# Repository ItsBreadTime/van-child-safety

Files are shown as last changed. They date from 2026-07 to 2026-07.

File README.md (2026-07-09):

# School Van Child Left-Behind Monitoring and Alert System

Prototype ESP32-based van child-safety monitor using BLE beacons, cabin sensors, MQTT/Home Assistant, and operator alerts for child-left-in-vehicle risk.

> Safety note: this is a research/prototype system, not a certified safety product. Do not rely on it as the only way to verify that a vehicle is empty. A physical cabin check and responsible operator procedure remain required.

## What It Does

- Reads ignition state from an ESP-NOW ignition remote or a protected GPIO input.
- Tracks cabin evidence from BLE iBeacon tags, LD2412 mmWave presence, SCD4x CO2, SHT4x temperature/humidity, and optional GPS.
- Publishes telemetry, state, roster, command, and distress topics over MQTT.
- Integrates with Home Assistant through MQTT discovery and optional YAML templates.
- Sends readable Discord bot alerts through a local Python relay.
- Supports guarded disarm workflows that require explicit cabin-clear confirmation.

## Repository Layout

```text
main/                 ESP-IDF firmware for the main ESP32-S3 unit
ignition_remote/      ESP-NOW heartbeat firmware for an ignition-powered remote
discord_relay/        Python Discord/MQTT relay with tests and Docker support
homeassistant/        Sanitized Home Assistant package/dashboard templates
hardware/             PCB, enclosure, and manufacturing/export files
docs/                 Public setup, configuration, protocol, and safety docs
test_runs/            Sanitized validation evidence and raw logs
```

The Android/mobile beacon app, thesis/report narrative drafts, private configs, generated office documents, and unsanitized runtime artifacts are intentionally not included in this public export. Sanitized validation evidence is included under [test_runs](test_runs/).

## Quick Start

1. Install ESP-IDF 5.x for `esp32s3`.
2. Copy `main/secrets.h.example` to `main/secrets.h` and fill in your own Wi-Fi, WireGuard, MQTT, and OTA values.
3. Build the firmware:

```bash
idf.py set-target esp32s3
idf.py build
```

4. Flash over USB:

```bash
idf.py -p /dev/cu.usbserial-XXXX flash monitor
```

5. Configure the relay:

```bash
cd discord_relay
cp .env.example .env
docker compose up -d --build
```

See [docs/SETUP.md](docs/SETUP.md) for the full setup path.

## Documentation

- [Setup](docs/SETUP.md)
- [Configuration](docs/CONFIGURATION.md)
- [MQTT contract](docs/MQTT.md)
- [Home Assistant templates](docs/HOME_ASSISTANT.md)
- [Hardware](docs/HARDWARE.md)
- [Flashing and OTA](docs/FLASHING.md)
- [Safety model](docs/SAFETY.md)
- [Sanitized test evidence](test_runs/)

## Tests

```bash
python -m pip install -r discord_relay/requirements.txt -r discord_relay/requirements-test.txt
python -m pytest discord_relay/tests -q
```

## License

Software is licensed under the Apache License 2.0. Hardware design files under `hardware/` are licensed under CERN-OHL-S v2; see [hardware/LICENSE](hardware/LICENSE).

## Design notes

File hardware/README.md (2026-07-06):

# Hardware Design

Hardware source and manufacturing/export files for the Van Child Safety prototype.

| Subdir | Source tool | Contents |
|---|---|---|
| `pcb/` | EasyEDA | Schematic, PCB render, Gerbers, EasyEDA JSON |
| `enclosure/` | Onshape | STEP/STL enclosure exports and assembly render |

## License

Hardware designs in this directory are licensed under CERN-OHL-S v2. See `hardware/LICENSE`.

Software in the rest of the repository is licensed under Apache 2.0.

## Notes

The PCB and enclosure files are provided as prototype artifacts. Validate footprints, clearances, power, thermal behavior, sensor placement, and enclosure materials before adapting them for a real vehicle.

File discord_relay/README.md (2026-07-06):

# Discord Relay

Dockerized Python relay that subscribes to the Van Child Safety MQTT topics, sends Discord bot alerts, and optionally exposes operator-only slash commands for status, guarded disarm, and beacon roster management.

## Setup

```bash
cp .env.example .env
docker compose up -d --build
```

Configure `.env` with your own MQTT broker, Discord bot token, channel IDs, and operator allow-list values.

## MQTT Inputs

- `bus/state`
- `bus/telemetry`
- `bus/beacon/+/state`
- `bus/beacon/config/state`
- `bus/distress/state`
- `bus/event`
- `bus/ha/location/event`
- `bus/ha/location/state`
- `bus/command/result`
- `bus/beacon/config/result`

## MQTT Outputs

- `bus/relay/discord/status`
- `bus/relay/discord/last_event`
- `bus/relay/discord/error`
- `bus/command`
- `bus/beacon/config/set`

## Operator Commands

Slash commands are disabled unless `DISCORD_COMMAND_GUILD_ID` and at least one operator user or role allow-list are configured.

- `/bus_status`
- `/disarm confirm:true`
- `/beacon list`
- `/beacon refresh`
- `/beacon add`
- `/beacon update`
- `/beacon active`
- `/beacon remove confirm:true`

`/disarm` is fail-closed: the caller must be allow-listed, `confirm` must be true, MQTT and firmware must be online, and success is shown only after matching firmware confirmation.

## Health And Metrics

The relay exposes:

- `GET /health`
- `GET /metrics`

The Docker image runs as a non-root user and writes logs/state under `/data`.

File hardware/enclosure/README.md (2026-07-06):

# Enclosure

Two-piece 3D-printed enclosure exports.

| File | Purpose |
|---|---|
| `top.step` | Top shell CAD export |
| `top.stl` | Top shell printable mesh |
| `bottom.step` | Bottom shell CAD export |
| `bottom.stl` | Bottom shell printable mesh |
| `assembly.png` | Assembly render |

STEP and STL exports preserve the final geometry, not the full parametric model history.

## Design Checks

- Keep antennas clear of metal.
- Do not block the LD2412 radar path with dense or metallic material.
- Give GPS a sky-facing path if used.
- Confirm heat, vibration, and mounting safety before any vehicle use.

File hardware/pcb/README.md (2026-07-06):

# PCB

PCB schematic, layout, and manufacturing exports.

| File | Purpose |
|---|---|
| `schematic.pdf` | Schematic export |
| `pcb.pdf` | PCB layout render |
| `pcb_top.pdf` | Top-side render |
| `pcb_bottom.pdf` | Bottom-side render |
| `gerber.zip` | Gerber manufacturing package |
| `pcb_easyeda.json` | EasyEDA-native editable source |
| `pcb_3d.obj` | Generated 3D board export |

Review all footprints, pin assignments, regulator/current limits, mounting holes, and connector clearances before manufacturing.

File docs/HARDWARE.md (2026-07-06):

# Hardware

The prototype uses:

- ESP32-S3 board with PSRAM
- SCD4x CO2 sensor
- SHT4x temperature/humidity sensor
- HLK-LD2412 mmWave presence sensor
- GPS receiver, optional
- BLE/iBeacon tags
- Ignition-powered ESP32 remote, optional but recommended
- Carrier PCB and 3D-printed enclosure under `hardware/`

## Main Firmware Pin Map

| Function | Default |
|---|---|
| I2C SDA | GPIO5 |
| I2C SCL | GPIO6 |
| LD2412 UART TX from ESP32 | GPIO7 |
| LD2412 UART RX to ESP32 | GPIO8 |
| GPS UART RX | GPIO9 |
| Legacy ignition GPIO | GPIO4 |

Check `main/Kconfig.projbuild` and the PCB files before wiring a different board.

## Enclosure Notes

- Keep the ESP32 antenna clear of metal.
- Give the GPS antenna a reasonable sky view if GPS is used.
- Do not place thick FR4 or metal directly in front of the LD2412 radar path.
- Validate thermal behavior and power stability in the actual enclosure before field use.

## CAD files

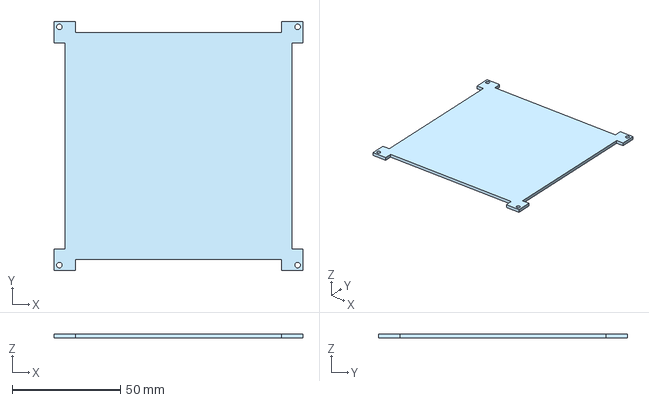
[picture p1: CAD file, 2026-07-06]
hardware/enclosure/bottom.step
115.0 x 115.0 x 2.00 mm

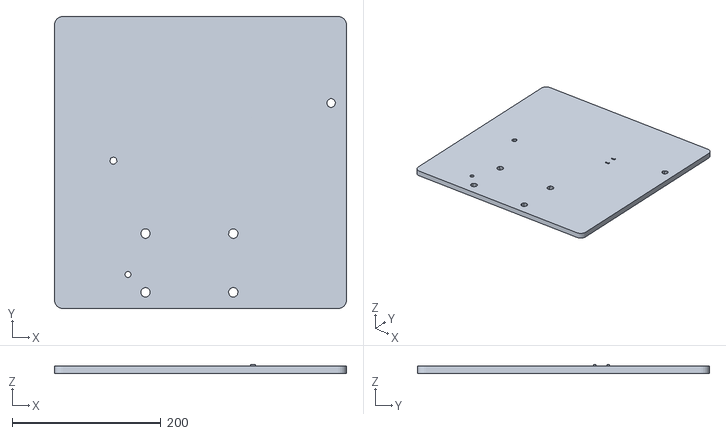
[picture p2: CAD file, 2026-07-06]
hardware/pcb/pcb_3d.obj
392.5 x 392.5 x 11.8

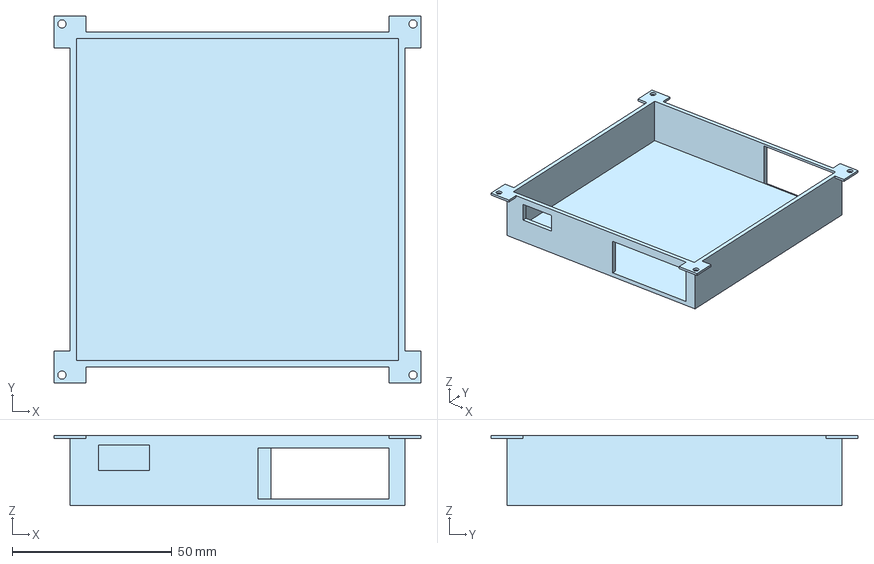
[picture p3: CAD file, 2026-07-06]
hardware/enclosure/top.step
115.0 x 115.0 x 22.0 mm

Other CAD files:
hardware/enclosure/bottom.stl
hardware/enclosure/top.stl

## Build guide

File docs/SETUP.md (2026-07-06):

# Setup

## Prerequisites

- ESP-IDF 5.x with ESP32-S3 support
- Python 3.12 for the relay and tests
- Docker or another Python runtime for the relay
- MQTT broker reachable from the firmware and relay
- Home Assistant with MQTT integration, if using the HA templates

## Firmware

```bash
cp main/secrets.h.example main/secrets.h
idf.py set-target esp32s3
idf.py menuconfig
idf.py build
idf.py -p /dev/cu.usbserial-XXXX flash monitor
```

Fill `main/secrets.h` with your own network, WireGuard, MQTT, and OTA values. Do not commit that file.

## Ignition Remote

The ignition remote is a separate ESP-IDF project. It broadcasts ESP-NOW heartbeats while powered by the vehicle ignition/accessory rail.

```bash
idf.py -C ignition_remote set-target esp32s3
idf.py -C ignition_remote menuconfig
idf.py -C ignition_remote -p /dev/cu.usbserial-XXXX flash monitor
```

The main firmware and remote firmware must use the same `ESPNOW_SECRET`.

## Discord Relay

```bash
cd discord_relay
cp .env.example .env
docker compose up -d --build
```

Set MQTT credentials, Discord bot token, channel IDs, and optional operator allow-lists in `.env`.

## Home Assistant

Start from the sanitized templates in `homeassistant/`. Adjust person/entity IDs, zone names, notification service names, and dashboard entity IDs for your own HA instance.

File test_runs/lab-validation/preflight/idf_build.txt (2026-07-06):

$ zsh -lc source '<local-path>' && idf.py build
# started_at=2026-07-04T19:00:24+07:00

Setting IDF_PATH to '<local-path>'
Detecting the Python interpreter
Checking "python3" ...
Python 3.14.4
"python3" has been detected
Checking Python compatibility
Checking other ESP-IDF version.
Adding ESP-IDF tools to PATH...
Checking if Python packages are up to date...
Python requirements are satisfied.
Constraint file: <local-path>
Requirement files:
 - <local-path>
Python being checked: <local-path>
Updated PATH variable:
  <local-path> Fusion.app/Contents/Public:<local-path>
Done! You can now compile ESP-IDF projects.
Go to the project directory and run:

  idf.py build

Executing action: all (aliases: build)
Running ninja in directory <local-path>
Executing "ninja all"...
[0/1] Re-running CMake...
-- Building ESP-IDF components for target esp32s3
NOTICE: Processing 2 dependencies:
NOTICE: [1/2] trombik/esp_wireguard (0.9.0)
NOTICE: [2/2] idf (5.3.3)
-- Project sdkconfig file <local-path>
Loading defaults file <local-path>
<local-path> CONFIG_APP_ROLLBACK_ENABLE was replaced with CONFIG_BOOTLOADER_APP_ROLLBACK_ENABLE 
-- Compiler supported targets: xtensa-esp-elf
CMake Deprecation Warning at <local-path> (cmake_minimum_required):
  Compatibility with CMake < 3.10 will be removed from a future version of
  CMake.

  Update the VERSION argument <min> value.  Or, use the <min>...<max> syntax
  to tell CMake that the project requires at least <min> but has been updated
  to work with policies introduced by <max> or earlier.

-- App "VanChildSafetySource" version: c19d455-dirty
-- Adding linker script <local-path>
-- Adding linker script <local-path>
-- Adding linker script <local-path>
-- Adding linker script <local-path>
-- Adding linker script <local-path>
-- Adding linker script <local-path>
-- Adding linker script <local-path>
-- Adding linker script <local-path>
-- Adding linker script <local-path>
-- Adding linker script <local-path>
-- Components: app_trace app_update bootloader bootloader_support bt cmock console cxx driver efuse esp-tls esp_adc esp_app_format esp_bootloader_format esp_coex esp_common esp_driver_ana_cmpr esp_driver_cam esp_driver_dac esp_driver_gpio esp_driver_gptimer esp_driver_i2c esp_driver_i2s esp_driver_isp esp_driver_jpeg esp_driver_ledc esp_driver_mcpwm esp_driver_parlio esp_driver_pcnt esp_driver_ppa esp_driver_rmt esp_driver_sdio esp_driver_sdm esp_driver_sdmmc esp_driver_sdspi esp_driver_spi esp_driver_touch_sens esp_driver_tsens esp_driver_uart esp_driver_usb_serial_jtag esp_eth esp_event esp_gdbstub esp_hid esp_http_client esp_http_server esp_https_ota esp_https_server esp_hw_support esp_lcd esp_local_ctrl esp_mm esp_netif esp_netif_stack esp_partition esp_phy esp_pm esp_psram esp_ringbuf esp_rom esp_system esp_timer esp_vfs_console esp_wifi espcoredump esptool_py fatfs freertos hal heap http_parser idf_test ieee802154 json log lwip main mbedtls mqtt newlib nvs_flash nvs_sec_provider openthread partition_table perfmon protobuf-c protocomm pthread sdmmc soc spi_flash spiffs tcp_transport touch_element trombik__esp_wireguard ulp unity usb vfs wear_levelling wifi_provisioning wpa_supplicant xtensa
-- Component paths: <local-path> <local-path> <local-path> <local-path> <local-path> <local-path> <local-path> <local-path> <local-path> <local-path> <local-path> <local-path> <local-path> <local-path> <local-path> <local-path> <local-path> <local-path> <local-path> <local-path> <local-path> <local-path> <local-path> <local-path> <local-path> <local-path> <local-path> <local-path> <local-path> <local-path> <local-path> <local-path> <local-path> <local-path> <local-path> <local-path> <local-path> <local-path> <local-path> <local-path> <local-path> <local-path> <local-path> <local-path> <local-path> <local-path> <local-path> <local-path> <local-path> <local-path> <local-path> <local-path> <local-path> <local-path> <local-path> <local-path> <local-path> <local-path> <local-path> <local-path> <local-path> <local-path> <local-path> <local-path> <local-path> <local-path> <local-path> <local-path> <local-path> <local-path> <local-path> <local-path> <local-path> <local-path> <local-path> <local-path> <local-path> <local-path> <local-path> <local-path> <local-path> <local-path> <local-path> <local-path> <local-path> <local-path> <local-path> <local-path> <local-path> <local-path> <local-path> <local-path> <local-path> <local-path> <local-path> <local-path> <local-path> <local-path> <local-path> <local-path> <local-path> <local-path> <local-path>
-- Configuring done (4.1s)
-- Generating done (0.4s)
-- Build files have been written to: <local-path>
[1/10] Performing build step for 'bootloader'
[1/1] cd <local-path> && <local-path> <local-path> --offset 0x8000 bootloader 0x0 <local-path>
Bootloader binary size 0x54e0 bytes. 0x2b20 bytes (34%) free.
[2/10] No install step for 'bootloader'
[3/10] Completed 'bootloader'
[4/10] Building C object esp-idf/esp_app_format/CMakeFiles/__idf_esp_app_format.dir/esp_app_desc.c.obj
[5/10] Linking C static library esp-idf/esp_app_format/libesp_app_format.a
[6/10] Generating ld/sections.ld
[7/10] Linking CXX executable VanChildSafetySource.elf
[8/10] Generating binary image from built executable
esptool.py v4.11.0
Creating esp32s3 image...
Merged 2 ELF sections
Successfully created esp32s3 image.
Generated <local-path>
[9/10] cd <local-path> && <local-path> <local-path> --offset 0x8000 partition --type app <local-path> <local-path>
VanChildSafetySource.bin binary size 0x176050 bytes. Smallest app partition is 0x300000 bytes. 0x189fb0 bytes (51%) free.

Project build complete. To flash, run:
 idf.py flash
or
 idf.py -p PORT flash
or
 python -m esptool --chip esp32s3 -b 460800 --before default_reset --after hard_reset write_flash --flash_mode dio --flash_size 8MB --flash_freq 80m 0x0 build/bootloader/bootloader.bin 0x8000 build/partition_table/partition-table.bin 0xf000 build/ota_data_initial.bin 0x20000 build/VanChildSafetySource.bin
or from the "<local-path>" directory
 python -m esptool --chip esp32s3 -b 460800 --before default_reset --after hard_reset write_flash "@flash_args"

# finished_at=2026-07-04T19:00:42+07:00
# exit_code=0

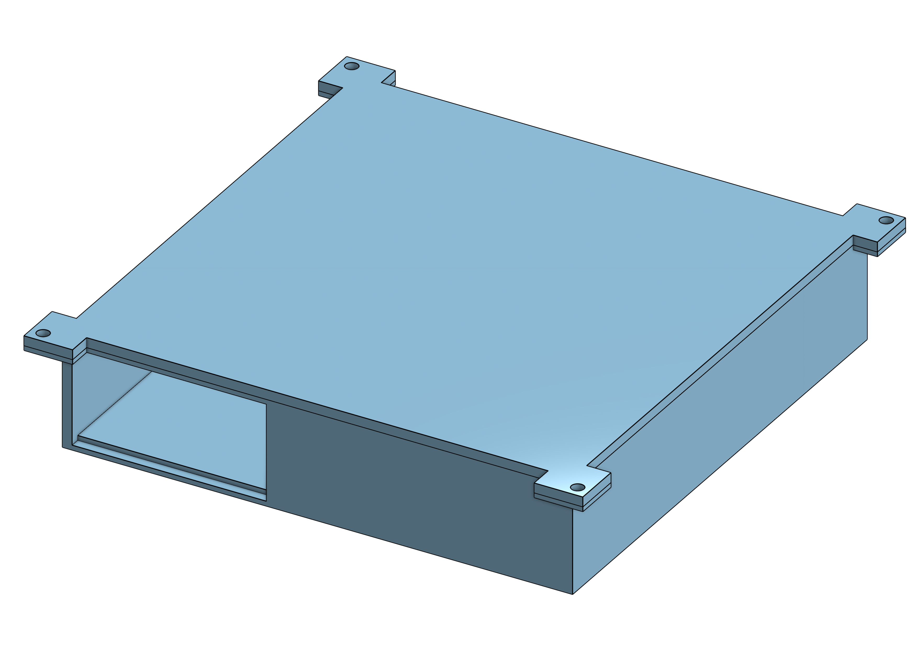
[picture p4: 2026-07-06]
hardware/enclosure/assembly.png

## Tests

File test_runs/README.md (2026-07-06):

# Public Test Run Evidence

This folder contains sanitized evidence captured during firmware, relay, Home Assistant, MQTT, sensor, and supervised real-van validation runs.

The files are included to show the shape of the evidence behind the prototype, not to claim certification or complete safety validation. The strongest interpretation is still bounded: these runs demonstrate subsystem behavior, MQTT/relay contracts, guarded operator commands, and one supervised adult-occupant real-van alarm path.

## Runs

| Run | Scope | Public-use boundary |
|---|---|---|
| [lab-validation](lab-validation/) | Simulated, desk-proxy, passive telemetry, relay, Home Assistant, command, and sensor checks. | Useful subsystem evidence; not a complete real-cabin child-left-in-van validation. |
| [field-validation](field-validation/) | Supervised real-van route and adult-occupant evidence. | Supports route notifications and a supervised adult-occupant alarm path; not an unattended-child or heat-risk test. |

## Sanitization

The child/beacon labels in the source evidence are treated as pseudonyms and are preserved. Discord IDs, local paths, private IPs/hosts, Home Assistant person/zone/device entities, UUIDs, MAC addresses, GPS fields, operator handles, and secret-like values were replaced with neutral placeholders.

Raw MQTT, relay, collector, and scenario logs are included after sanitization. The summary layer lives in the run `README.md`, `chapter4_summary.md`, and each scenario `result.md`.

Screenshots, launchd/plist/shell supervision wrappers, PID files, and temporary OS files were omitted because they were not needed to understand the evidence and are difficult to scrub reliably.

See [SANITIZATION.md](SANITIZATION.md) for details.

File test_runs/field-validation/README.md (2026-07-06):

# Chapter 4 Real-Van Evidence Run

Created at: `2026-07-05T13:10:41+07:00`
Git commit: `795deef`
Git branch: `main`
Run type: supervised real-van route and adult-occupant evidence.

## Start Here

Use [chapter4_summary.md](chapter4_summary.md) for the short scenario table.
This run is the strongest current real-van evidence in the archive, but it still
needs careful wording: the emergency scenario used a supervised adult occupant,
not an unattended child or heat-risk setup.

## Scenario Summary

| Scenario | Result | Best claim to make | Boundary |
|---|---|---|---|
| [T-REAL-VAN-OCCUPANT-01](T-REAL-VAN-OCCUPANT-01/) | pass, 1/1 | Supervised adult-occupant real-van test reached `distress_active`, published structured emergency MQTT evidence, and the remote Discord relay sent the emergency notification. | Not an unattended-child, heat-risk, or full operator-response test; no ack/disarm round was performed. |
| [T-REAL-VAN-ROUTE-01](T-REAL-VAN-ROUTE-01/) | partial, 2/3 evidence groups | Real BLE/route notifications and field telemetry capture worked during the supervised route. | Final armed/distress-pending segment was interrupted by network failure, so it is not a completed safety-detection round. |

## Key Evidence

- `T-REAL-VAN-OCCUPANT-01` captured a 120 s armed-to-distress interval and
  about 1 s MQTT-distress-to-remote-relay-send interval.
- `T-REAL-VAN-OCCUPANT-01` recorded the first distress as
  `distress-20260705-064807`, trigger `beacon_near`, detail `bread`, and person
  `Bread`.
- `T-REAL-VAN-ROUTE-01` observed routine Discord messages for entered-bus,
  exited-bus, exited-at-school, reached-home, and bus-reached-school events
  after the notification fix.
- Remote relay evidence is stronger than the local `relay_before.jsonl` and
  `relay_after.jsonl` snapshots for this run, because the active relay was on
  the remote host. Prefer `remote_relay.log` where present plus MQTT
  `bus/relay/discord/*` topics.

## Evidence Files

- Root snapshots: `manifest.json`, `config_snapshot.txt`, `git_commit.txt`,
  `git_branch.txt`, `git_status.txt`.
- Scenario logs: `mqtt.log`, `remote_relay.log` where available,
  `collector_supervisor.log`, `stop_collection.log`, launchd/caffeinate logs,
  and relay snapshots.
- Scenario data: `events.csv`, `rssi.csv`, `measurements.csv`, `co2.csv`.
- Screenshots are omitted from the public archive; the relevant notification
  and state evidence is preserved in sanitized logs and scenario result files.

The original private capture path and regeneration command were redacted; this
public export keeps the sanitized run under `test_runs/field-validation/`.

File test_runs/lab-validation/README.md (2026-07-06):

# Chapter 4 Simulated And Desk-Proxy Evidence Run

Created at: `2026-07-03T23:30:38+07:00`
Git commit: `4d69e42`
Git branch: `main`
Run type: simulated, passive, and desk-proxy subsystem evidence.

## Start Here

Use [chapter4_summary.md](chapter4_summary.md) as the table of contents for the
scenario results. It is the best single file for Chapter 4 writing because it
keeps the evidence boundaries attached to each result.

## How To Read This Run

This run is useful subsystem evidence, but it is not a full field validation of
the child-left-in-van safety claim. Most scenarios were simulated, passive, or
desk-proxy checks. They show that specific MQTT contracts, relay behavior,
command handling, and sensor telemetry paths worked during this session.

Do not cite a `pass` row as proof of real-cabin occupant detection unless the
scenario explicitly says it was a supervised van test. The completed armed BLE
and LD2412/mmWave trigger checks used `bus_empty_on` override and/or desk setup
conditions, so they are supporting evidence for firmware and relay behavior,
not final evidence of physical placement, RF propagation, cabin geometry, CO2
rise, or unattended-child safety.

The run metadata records Git commit `4d69e42`, while the preflight firmware
build log reports app version `854da60`. Treat the exact firmware-under-test
identity as requiring explanation before using this folder as archival evidence.

## Scenario Groups

| Group | Scenarios | Use for |
|---|---|---|
| BLE and beacon behavior | `T-BLE-*`, `T-ADVISORY-01` | Armed BLE trigger path, Bread beacon latency, active-state false-positive checks, and beacon-silent advisory behavior. |
| Relay behavior | `T-RELAY-*`, `T-ADVISORY-02`, `T-HA-ZONE-01` | Routine/warning/emergency relay formatting, dedupe, acknowledgement policy, sensor-fault advisory, and HA zone events. |
| Guarded operator commands | `T-DISARM-*` | Rejection of unsafe disarm commands, guarded disarm with cabin-clear confirmation, and command-result latency. |
| Ignition and ESP-NOW | `T-IGN-*` | Ignition heartbeat unplug/replug, rapid reconnect behavior, and an incomplete/failing timeout attempt. |
| Sensor telemetry | `T-SCD4X-*`, `T-SHT4X-*`, `T-LD2412-*`, `T-LD-ARMENTRY-01`, `T-GPS-01` | Passive telemetry freshness, desk-proxy mmWave trigger behavior, indoor no-fix GPS evidence, and placement/controllability caveats. |
| Home Assistant and retained MQTT | `T-HA-*`, `T-MQTT-*` | HA package/source-field checks, retained-state coherence, and short MQTT soak stability observations. |

## Key Outcomes

- Strongest BLE result: `T-BLE-03` produced Bread-specific simulated
  `distress_active`, retained distress, real Discord emergency output, and
  clean restoration with Crystal absent.
- Strongest command result: `T-DISARM-01` showed the guarded disarm workflow,
  while `T-DISARM-02` and `T-DISARM-02-LATENCY` showed unsafe disarm rejection.
- Useful negative results: `T-GPS-01` recorded indoor/no-fix GPS behavior, and
  `T-LD2412-PASSIVE-01` showed the LD2412 target did not clear during the
  intended passive movement test.
- Do not use `T-BLE-02` as a pass/fail result; it is marked invalid because the
  harness missed a transient state. Use `T-BLE-03` instead.
- `T-IGN-ESPNOW-03` has summary JSON but no `result.md` row in the generated
  summary; treat it as an incomplete/failing exploratory attempt unless it is
  rerun and documented.

## Evidence Files

- Root snapshots: `manifest.json`, `config_snapshot.txt`, `git_commit.txt`,
  `git_branch.txt`, `git_status.txt`.
- Preflight: `preflight/idf_build.txt`, `preflight/idf_size.txt`,
  `preflight/relay_pytest.txt`, `preflight/summary.json`.
- Scenario evidence: each scenario folder keeps its own `README.md`,
  `result.md` where available, MQTT logs, relay snapshots, and
  scenario-specific CSV/JSON evidence.

The original private capture path and regeneration command were redacted; this
public export keeps the sanitized run under `test_runs/lab-validation/`.

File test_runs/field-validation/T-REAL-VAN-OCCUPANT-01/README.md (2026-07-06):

# T-REAL-VAN-OCCUPANT-01

Environment: real van supervised adult occupant presence test
Date/time: 2026-07-05T13:38:40+07:00
Firmware commit: 795deef
Ignition source: live vehicle/installed system
Relevant config: Live MQTT bus/# capture plus remote Discord relay evidence; supervised adult occupant; do not lock occupant in; maintain exit path and outside observer
Round count planned: 1
Operator: operator
Supervisor: operator

Physical setup:
- Door/window state: unlocked exit path required; do not lock occupant in
- Fan/AC state: record actual state before and during test
- Sensor placement:
- Beacon placement:
- LD2412 target position:

Safety notes:
- Abort criteria: stop immediately for heat, discomfort, network uncertainty, loss of outside observer, or any blocked exit
- Actual abort condition reached: no at setup time

Automation notes:
- MQTT log: `mqtt.log`
- Serial log: `serial.log`
- Relay snapshots: `relay_before.jsonl`, `relay_after.jsonl`
- Measurements: `measurements.csv`, `co2.csv`, `rssi.csv`

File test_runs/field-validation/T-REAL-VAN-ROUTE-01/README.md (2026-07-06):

# T-REAL-VAN-ROUTE-01

Environment: real van route / drop-off and pick-up field test
Date/time: 2026-07-05T13:10:41+07:00
Firmware commit: 795deef
Ignition source: live vehicle/installed system
Relevant config: Live MQTT bus/# capture plus remote Discord relay evidence; relay notifications fixed in commit 795deef; broker 192.0.2.10; relay host 192.0.2.10
Round count planned: 3
Operator: operator
Supervisor: operator

Physical setup:
- Door/window state:
- Fan/AC state:
- Sensor placement:
- Beacon placement:
- LD2412 target position:

Safety notes:
- Abort criteria:
- Actual abort condition reached: yes/no

Automation notes:
- MQTT log: `mqtt.log`
- Serial log: `serial.log`
- Relay snapshots: `relay_before.jsonl`, `relay_after.jsonl`
- Measurements: `measurements.csv`, `co2.csv`, `rssi.csv`

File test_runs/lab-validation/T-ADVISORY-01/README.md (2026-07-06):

# T-ADVISORY-01

Environment: simulated
Date/time: 2026-07-04T19:16:59+07:00
Firmware commit: 4d69e42
Ignition source: 
Relevant config: Bread iBeacon near at arming, then transmitter stopped until absent; observe beacon_silent_while_armed event
Round count planned: 1
Operator: operator
Supervisor: 

Physical setup:
- Door/window state:
- Fan/AC state:
- Sensor placement:
- Beacon placement:
- LD2412 target position:

Safety notes:
- Abort criteria:
- Actual abort condition reached: yes/no

Automation notes:
- MQTT log: `mqtt.log`
- Serial log: `serial.log`
- Relay snapshots: `relay_before.jsonl`, `relay_after.jsonl`
- Measurements: `measurements.csv`, `co2.csv`, `rssi.csv`

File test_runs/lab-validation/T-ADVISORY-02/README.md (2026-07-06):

# T-ADVISORY-02

Environment: simulated-mqtt
Date/time: 2026-07-04T19:18:39+07:00
Firmware commit: 4d69e42
Ignition source: 
Relevant config: publish bus/event sensor_fault; observe relay advisory handling
Round count planned: 1
Operator: operator
Supervisor: 

Physical setup:
- Door/window state:
- Fan/AC state:
- Sensor placement:
- Beacon placement:
- LD2412 target position:

Safety notes:
- Abort criteria:
- Actual abort condition reached: yes/no

Automation notes:
- MQTT log: `mqtt.log`
- Serial log: `serial.log`
- Relay snapshots: `relay_before.jsonl`, `relay_after.jsonl`
- Measurements: `measurements.csv`, `co2.csv`, `rssi.csv`

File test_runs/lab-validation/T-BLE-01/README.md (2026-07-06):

# T-BLE-01

Environment: simulated
Date/time: 2026-07-04T12:07:53+07:00
Firmware commit: 4d69e42
Ignition source: 
Relevant config: armed BLE child-beacon detection using bus_empty_on override and automated Bread iBeacon transmitter; real Discord distress allowed
Round count planned: 1
Operator: 
Supervisor: 

Physical setup:
- Door/window state:
- Fan/AC state:
- Sensor placement:
- Beacon placement:
- LD2412 target position:

Safety notes:
- Abort criteria:
- Actual abort condition reached: yes/no

Automation notes:
- MQTT log: `mqtt.log`
- Serial log: `serial.log`
- Relay snapshots: `relay_before.jsonl`, `relay_after.jsonl`
- Measurements: `measurements.csv`, `co2.csv`, `rssi.csv`

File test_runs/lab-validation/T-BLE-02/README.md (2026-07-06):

# T-BLE-02

Environment: simulated
Date/time: 2026-07-04T12:44:00+07:00
Firmware commit: 4d69e42
Ignition source: 
Relevant config: isolated armed BLE child-beacon detection using bus_empty_on override and automated Bread iBeacon transmitter; Crystal absent; real Discord distress allowed
Round count planned: 1
Operator: 
Supervisor: 

Physical setup:
- Door/window state:
- Fan/AC state:
- Sensor placement:
- Beacon placement:
- LD2412 target position:

Safety notes:
- Abort criteria:
- Actual abort condition reached: yes/no

Automation notes:
- MQTT log: `mqtt.log`
- Serial log: `serial.log`
- Relay snapshots: `relay_before.jsonl`, `relay_after.jsonl`
- Measurements: `measurements.csv`, `co2.csv`, `rssi.csv`

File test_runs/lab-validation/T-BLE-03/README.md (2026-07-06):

# T-BLE-03

Environment: simulated
Date/time: 2026-07-04T12:46:00+07:00
Firmware commit: 4d69e42
Ignition source: 
Relevant config: isolated armed BLE child-beacon detection rerun using bus_empty_on override and automated Bread iBeacon transmitter; Crystal absent; real Discord distress allowed; corrected harness preserves transient armed state
Round count planned: 1
Operator: 
Supervisor: 

Physical setup:
- Door/window state:
- Fan/AC state:
- Sensor placement:
- Beacon placement:
- LD2412 target position:

Safety notes:
- Abort criteria:
- Actual abort condition reached: yes/no

Automation notes:
- MQTT log: `mqtt.log`
- Serial log: `serial.log`
- Relay snapshots: `relay_before.jsonl`, `relay_after.jsonl`
- Measurements: `measurements.csv`, `co2.csv`, `rssi.csv`

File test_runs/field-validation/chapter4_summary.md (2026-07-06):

# Chapter 4 Scenario Summary

Generated at: 2026-07-05T13:52:03+07:00

## Reader Summary

This is the strongest current real-van evidence folder. It supports two
different claims:

- `T-REAL-VAN-OCCUPANT-01` supports the supervised real-van emergency path:
  armed state, occupant/beacon evidence, `distress_active`, structured MQTT
  distress payload, and remote Discord emergency delivery were all observed.
- `T-REAL-VAN-ROUTE-01` supports real route/attendance notifications and field
  telemetry capture, but the final armed segment is only partial because a
  network failure interrupted the run before completed distress evidence was
  captured.

Do not combine these into a single broad claim that the whole unattended-child
system is fully validated. The safe wording is: real-van route notifications
were field-observed, and a supervised adult-occupant emergency path was
successfully demonstrated.

## Scenario Table

| Scenario ID | Environment | Setup | Rounds passed/total | Result | Chapter 4 notes |
|---|---|---|---:|---|---|
| T-REAL-VAN-OCCUPANT-01 | real van supervised adult occupant presence test | Live MQTT bus/# capture plus remote Discord relay evidence; supervised adult occupant; do not lock occupant in; maintain exit path and outside observer | 1/1 | pass | - This run supports the real-van supervised adult occupant alarm path: after arming, the system detected the carried beacon/presence condition, entered `distress_active`, published a structured emergency distress payload, and the relay delivered the emergency Discord notification. - The strongest timing claim from this run is a 120 s armed-to-distress interval and about 1 s MQTT-distress-to-relay-send interval. - This is a controlled adult-occupant safety test, not an unattended-child or heat-risk test. The Chapter 4 wording should preserve that boundary. - Use `remote_relay.log` and MQTT `bus/relay/discord/*` topics as relay evidence. The helper's local `relay_before.jsonl` and `relay_after.jsonl` snapshots are not authoritative for the remote relay host. |
| T-REAL-VAN-ROUTE-01 | real van route / drop-off and pick-up field test | Live MQTT bus/# capture plus remote Discord relay evidence; relay notifications fixed in commit 795deef; broker 192.0.2.10; relay host 192.0.2.10 | 2/3 observed evidence groups | partial | - This run supports the fixed routine Discord relay path for real BLE beacon transitions during a supervised route: entered-bus, exited-bus, exited-at-school, reached-home, and bus-reached-school messages were observed after the notification fix. - This run also supports that MQTT evidence collection can stay active during a live field route when owned by launchd/caffeinate, and it produced usable state, telemetry, RSSI, HA-location, and relay-status evidence. - The final armed/distress-pending segment is only partial evidence. It shows arming and `distress_pending`, but not a completed distress notification or clean recovery, because a network failure made the firmware appear offline before collection stopped. - Do not use this run alone to claim full real-van child-left-in-van validation. It is strongest as evidence for live route attendance notifications and field telemetry capture. |

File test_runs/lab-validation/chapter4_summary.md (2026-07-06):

# Chapter 4 Scenario Summary

Generated at: 2026-07-04T19:21:01+07:00

## Evidence Boundary

This table summarizes useful subsystem evidence, not a complete real-van
validation. A `pass` result means the scenario's stated condition was observed
in this run. It does not automatically mean the physical child-left-in-van
requirement has been proven. Simulated MQTT events, Android BLE transmission,
`bus_empty_on` override, desk-proxy LD2412/mmWave setup, and passive telemetry
observations should be reported with those qualifiers intact.

Known evidence caveat: session metadata records Git commit `4d69e42`, while the
preflight build log reports firmware app version `854da60`. Explain this before
using the run as a precise firmware traceability artifact.

## Reader Summary

Use this run for subsystem and contract evidence. The strongest positive
results are the corrected isolated BLE trigger path (`T-BLE-03`), guarded disarm
workflow (`T-DISARM-01` and `T-DISARM-02*`), relay policy checks
(`T-RELAY-*`), retained MQTT coherence (`T-MQTT-RETAINED-01`), and passive
telemetry visibility (`T-SCD4X-PASSIVE-01`, `T-SHT4X-01`, `T-MQTT-SOAK-*`).

The most important caveats are also useful Chapter 4 evidence: `T-GPS-01`
records an indoor no-fix condition, `T-LD2412-PASSIVE-01` shows the desk-proxy
target did not clear as intended, and `T-BLE-02` is invalid because the harness
missed a transient state. `T-IGN-ESPNOW-03` has a summary JSON but no
`result.md` entry in this table, so treat it as an incomplete/failing
exploratory attempt unless rerun.

## Scenario Table

| Scenario ID | Environment | Setup | Rounds passed/total | Result | Chapter 4 notes |
|---|---|---|---:|---|---|
| T-ADVISORY-01 | simulated | Bread iBeacon near at arming, then transmitter stopped until absent; observe beacon_silent_while_armed event | 1/1 | pass | T-ADVISORY-01 passed 1/1 simulated advisory round. Firmware emitted `beacon_silent_while_armed` for Bread after a near-to-absent transition while armed. This validates the advisory event path in the simulated setup; it is not a real-van beacon battery-loss validation. |
| T-ADVISORY-02 | simulated-mqtt | publish bus/event sensor_fault; observe relay advisory handling | 1/1 | pass | T-ADVISORY-02 passed 1/1 simulated MQTT advisory round. This validates relay handling of a `sensor_fault` advisory event. It does not prove firmware detects a disconnected or failed LD2412/SCD4x sensor. |
| T-BLE-01 | simulated | armed BLE child-beacon detection using bus_empty_on override and automated Bread iBeacon transmitter; real Discord distress allowed | 1/1 | pass | This is useful armed BLE-trigger evidence, but not identity-isolated evidence. The setup used firmware `bus_empty_on` override and an automated Android Bread iBeacon transmitter, while Crystal was also near. The observed distress identified Crystal, so report this as "an armed BLE distress and relay path fired with multiple near beacons present," not as Bread-specific validation. |
| T-BLE-02 | simulated | isolated armed BLE child-beacon detection using bus_empty_on override and automated Bread iBeacon transmitter; Crystal absent; real Discord distress allowed | 0/0 | invalid | Do not use this attempt as a system pass/fail result. It is useful as harness evidence: retained-state polling can miss a transient `armed` state when firmware advances quickly to `distress_pending`. Use `T-BLE-03` for the corrected isolated Bread-only armed BLE child-beacon detection result. |
| T-BLE-03 | simulated | isolated armed BLE child-beacon detection rerun using bus_empty_on override and automated Bread iBeacon transmitter; Crystal absent; real Discord distress allowed; corrected harness preserves transient armed state | 1/1 | pass | This is the strongest BLE result in this run: with Crystal absent, the Android Bread transmitter plus `bus_empty_on` override produced Bread-specific `distress_active`, retained distress, real Discord emergency output, and clean restoration. Report it as simulated end-to-end BLE trigger evidence, not as real-van RF placement validation. |
| T-BLE-BREAD-LATENCY | simulated | automated Android BLE test transmitter for Bread iBeacon; observe bus/beacon/bread/state | 10/10 | pass | This is a simulated BLE transmitter latency test, not a BeaconScope UI latency test. It isolates the bus BLE scanner/MQTT reporting path using the same Bread iBeacon UUID/major/minor. |
| T-BLE-FP-03 | simulated | Android Bread iBeacon transmitter stopped; observe absent and no distress while active | 1/1 | pass | T-BLE-FP-03 passed 1/1 simulated absent-beacon round. This supports the absent state/no-distress behavior while the bus is active. It does not test armed-state RSSI threshold false positives or real-van RF multipath. |
| T-BLE-FP-ACTIVE-01 | simulated | automated Bread iBeacon toggle while ignition_on active; verify no distress and bounded beacon chatter | 6/6 | pass | This is useful active-state false-positive evidence: repeated Bread near/absent transitions did not arm the bus or raise distress while ignition was on. It should not be generalized to armed-state false positives, marginal RSSI threshold behavior, or real-van RF multipath. |
| T-DISARM-01 | simulated | distress_test + distress_ack + guarded disarm with confirm_cabin_clear=true | 1/1 | pass | T-DISARM-01 passed 1/1 simulated guarded-disarm workflow round. The test observed intentional distress, acknowledgement, matching guarded disarm command result, actual `bus/state=disarmed`, and clean restoration to active/clear. This is command/state-machine evidence, not a substitute for a human cabin inspection. |
| T-DISARM-02 | simulated | invalid disarm without cabin-clear confirmation while bus is active | 3/3 | pass | T-DISARM-02 passed 3/3 simulated command rounds. Firmware rejected disarm without cabin-clear confirmation and did not transition to `disarmed`. Evidence: `mqtt.log` lines for `bus/command`, `bus/command/result`, and `bus/state`. |
| T-DISARM-02-LATENCY | simulated | 10-round invalid disarm command-result latency measurement while bus is active | 10/10 | pass | T-DISARM-02-LATENCY passed 10/10 simulated invalid-command rounds. Firmware rejected all invalid disarm commands and did not transition to `disarmed`. Matching command-result latency was min 35.6 ms, median 45.3 ms, mean 72.4 ms, and max 310.5 ms. Evidence: `command_latency.csv`, `latency_summary.json`, and `latency_events.jsonl`. |
| T-GPS-01 | simulated | passive GPS fix/no-fix observation from bus/state and bus/location/state | 0/1 | fail | Failed the intended GPS-fix criterion: the system reported `gps_valid=false` and no retained location arrived during the capture window. Treat this as honest indoor no-fix evidence, not as GPS validation. It is useful because it records what the system reports when no fix is available. |
| T-HA-01 | simulated-static | pytest discord_relay/tests/test_ha_package.py -q; YAML/package/dashboard structural audit only | 1/1 | pass | T-HA-01 passed 1/1 automated static audit round. This supports the Home Assistant package/dashboard configuration structure, not a live browser screenshot or deployed Home Assistant runtime state. |
| T-HA-IGN-01 | simulated-mqtt | bus_empty_on/off override; observe MQTT bus/state fields consumed by HA entities | 1/1 | pass | T-HA-IGN-01 passed 1/1 simulated MQTT-source round. The state fields consumed by Home Assistant updated across the ignition override transition. This should be reported as MQTT source-state evidence, not live dashboard rendering evidence. |
| T-HA-ZONE-01 | simulated | publish bus/ha/location/event zone_enter/zone_leave | 3/3 | pass | T-HA-ZONE-01 passed 3/3 simulated MQTT rounds. The relay accepted HA zone-event payloads and produced non-emergency advisory output; relay status remained online and error clear. Evidence: `mqtt.log`, `events.csv`, and retained `bus/relay/discord/last_event` after the run. This does not validate Home Assistant dashboard rendering, entity templates, mobile geofencing, or real zone transitions. |
| T-IGN-ESPNOW-01 | simulated | ESP-NOW remote unplug while active; observe ok to stale and active to exit_grace, then replug before armed distress | 1/1 | pass | T-IGN-ESPNOW-01 passed 1/1 supervised simulated round. ESP-NOW remote unplug produced `ok` to `stale` and `active` to `exit_grace`; replug restored `ok` and `active`. Evidence: `mqtt.log` lines for `bus/state`, `bus/event` (`ignition_off`, `ignition_on`), and relay status. |
| T-IGN-RAPID-01 | simulated | rapid ESP-NOW remote unplug/replug under 5 seconds; expected no stale timeout or false state transition | 1/1 | pass | T-IGN-RAPID-01 passed 1/1 supervised simulated round. A rapid ESP-NOW remote unplug/replug did not produce `ignition_source_status=stale`, `ignition_off`, `exit_grace`, `armed`, or distress. Evidence: `mqtt.log`, `measurements.csv`, and `relay_after.jsonl`. |
| T-LD-ARMENTRY-01 | simulated | desk proxy LD2412/mmWave armed trigger with target already present at arm time; real Discord distress allowed; fallback because passive target did not clear | 1/1 | pass | This test shows that the LD2412/mmWave `presence_detected` firmware and relay path can fire in a simulated desk environment when a target is already present at arming. It should be reported as desk-proxy trigger-path evidence only. It does not prove target clear/re-detect behavior, real-seat coverage, or real-cabin occupant detection. |
| T-LD2412-PASSIVE-01 | simulated | active-state LD2412/mmWave target movement observation; user moves out of and back into sensor range; no arming | 0/1 | fail | Failed the intended controllability criterion because the target never cleared to `ld2412_target=false`. This is a valuable negative result: distance and energy changed, but the binary target state stayed latched. Do not claim LD2412 placement is validated from this run; use it to justify placement/reflection retesting. |
| T-MQTT-RETAINED-01 | simulated | retained MQTT state coherence audit across bus, beacon, distress, relay topics | 1/1 | pass | This is a retained-state coherence snapshot across core MQTT topics. It is useful evidence that the retained state was coherent at capture time, but it should not be treated as proof that retained metadata cannot go stale after future distress, clear, relay reconnect, or roster updates. |
| T-MQTT-SOAK-01 | simulated | passive 5-minute MQTT soak/jitter observation while bus is active | 1/1 | pass | Passive short soak; useful for reporting observed MQTT cadence and active-state live-system stability. It does not exercise arming, distress generation, reconnect recovery, operator commands, or physical detection triggers. |
| T-MQTT-SOAK-02 | simulated | 15-minute passive MQTT soak/jitter observation while bus is active | 1/1 | pass | Passive extended soak; useful for reporting telemetry cadence, retained live-state stability, relay health, and passive SCD4x/CO2 plus LD2412/mmWave telemetry visibility. This does not prove CO2-rise or mmWave-presence distress trigger correctness because the bus remained active (`ignition_on=true`, `bus_armed=false`) and no controlled sensor stimulus was applied. Also report that retained relay status showed `operator_commands_enabled=false` and `operator_gateway_ready=false`, so this run should not be used as operator-command readiness evidence. |
| T-RELAY-01 | simulated | publish simulated MQTT events: routine/warning/emergency | 3/3 | pass | T-RELAY-01 passed 3/3 simulated relay severity rounds. Routine, warning, and emergency MQTT inputs were reflected in relay output with matching severity (`emergency=false` for routine/warning, `emergency=true` for distress). Evidence: `mqtt.log`, `events.csv`, and retained `bus/relay/discord/last_event`. This supports relay policy for synthetic payloads, not firmware sensor detection. |
| T-RELAY-02 | simulated | publish repeated distress with same distress id | 3/3 | pass | T-RELAY-02 passed 3/3 simulated dedupe rounds. The relay sent the first emergency for `ch4-relay-02-dedupe` and suppressed repeated same-ID distress publishes within the repeat interval. Evidence: `mqtt.log` lines for the three distress payloads and the single matching emergency `last_event`. |
| T-RELAY-03 | simulated | acknowledged distress flow and mention policy | 3/3 | pass | T-RELAY-03 passed 3/3 simulated acknowledgement-policy rounds. The relay sent the initial emergency notification, accepted the acked distress payload, and suppressed the repeated active distress payload after acknowledgement. Evidence: `mqtt.log` lines for active, acked, repeated active, and the single emergency `last_event`. |
| T-SCD4X-PASSIVE-01 | simulated | fresh passive SCD4x/CO2 telemetry and freshness observation while bus remains active; no CO2 trigger stimulus | 1/1 | pass | This test supports the narrow claim that SCD4x/CO2 telemetry was fresh and plausible in the simulated/desk environment during this short passive window. It does not validate the `co2_rise` distress trigger, cabin airflow behavior, threshold tuning, or emergency escalation. |
| T-SHT4X-01 | simulated | passive MQTT telemetry observation of SHT4x temperature/RH while bus is active | 1/1 | pass | Passive temperature/RH telemetry presence and plausibility check only. No heat, humidity, enclosure, or van environmental response was tested. |

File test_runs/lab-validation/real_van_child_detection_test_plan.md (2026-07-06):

# Real Van Child-Detection Test Plan

## Purpose

This run has not yet validated the core end-to-end behavior: detecting an
occupant left inside a real van after ignition-off arming. The supporting
systems have been tested, but Chapter 4 still needs real-van evidence for the
detection paths themselves: BLE beacon, LD2412 mmWave presence, CO2 rise, and
the integrated distress/relay cycle.

This plan uses a supervised adult volunteer and/or beacon/dummy setup. Do not
use an unattended child, do not lock anyone inside, and do not create a heat-risk
condition.

## Roles

- Safety supervisor: outside the van, has key, watches the person, can open the
  door immediately.
- Test subject: adult volunteer only, seated in the target seat.
- Operator: runs MQTT/serial/Discord evidence capture and timestamps actions.
- Observer: records door/window/fan/AC state, cabin temperature, and photos.

One person may fill operator/observer roles, but the safety supervisor should be
dedicated during any occupied-van round.

## Safety Rules

- Use a shaded/cool location; avoid midday heat.
- Doors remain unlocked. Safety supervisor stays beside the van.
- Subject keeps phone/voice contact with supervisor.
- Abort immediately if subject is uncomfortable, cabin temperature rises beyond
  the chosen limit, power behaves unexpectedly, or the system enters an
  unexpected state.
- Suggested conservative abort thresholds:
  - cabin temperature >= 30 C, or lower if subject feels warm;
  - any dizziness, shortness of breath, anxiety, or discomfort;
  - round duration exceeds planned maximum;
  - Discord/relay/emergency state cannot be cleared after the round.
- Keep each occupied round short. BLE and LD2412 rounds should complete within
  seconds to tens of seconds after arming. CO2 rounds may need longer, so use
  extra caution and stop as soon as the trigger/evidence is sufficient.

## Required Evidence

For every scenario:

- `mqtt.log` covering `bus/state`, `bus/telemetry`, `bus/event`,
  `bus/distress/state`, `bus/beacon/+/state`, relay topics.
- Serial log if available.
- Relay before/after JSONL snapshots.
- Discord screenshot for emergency and clear/ack/disarm flow if real Discord is
  used.
- Home Assistant screenshot if dashboard evidence is needed.
- Photo of setup: sensor placement, subject seat, beacon placement.
- Manual notes: weather, ambient/cabin temperature, window state, door state,
  fan/AC state, ignition remote action time, subject position.
- Metrics: time from ignition-off/armed to distress, trigger source, CO2/RSSI
  trend, LD2412 distance/energy/target state, relay notification latency.

## Preflight

1. Confirm relay online and error clear.
2. Confirm `bus/state` starts as:
   - `state=active`
   - `ignition_on=true`
   - `armed=false`
   - `distress_active=false`
   - sensor statuses acceptable.
3. Confirm the operator can clear the test condition by turning ignition back on
   and, only after explicit confirmation, using the normal ack/disarm workflow.
4. Start evidence capture before changing ignition state.
5. Confirm real Discord alerts are acceptable for this test round, or redirect
   to a test channel if available.

## Scenario 1: Empty Van False-Positive Baseline

IDs covered: `T-CO2-FP-02`, `T-LD-FP-03`, `T-BLE-FP-03`, optionally
`T-BUSCLEAR-01`.

Procedure:

1. Remove child beacons or keep them far enough to be absent.
2. Confirm no person is inside and LD2412 target is false if practical.
3. Turn ignition remote off and allow system to enter `armed`.
4. Observe for the planned window, for example 3-5 minutes.
5. Expected: no distress. If implemented, `bus_clear` may appear when cabin is
   clear.
6. Turn ignition back on and record final state.

Pass criteria:

- No `distress_active=true`.
- No emergency Discord notification.
- Sensor/relay state remains coherent.

## Scenario 2: BLE Beacon Detection In Van

IDs covered: `T-BLE-02`.

Procedure:

1. Place Bread beacon/phone on the target seat where a child bag/tag would be.
2. No person is required for this round.
3. Confirm `bus/beacon/bread/state` becomes `near`.
4. Turn ignition remote off and allow the system to arm.
5. Expected: after BLE near sustain, distress triggers with beacon evidence.
6. Capture Discord alert and `bus/distress/state`.
7. Turn ignition back on. Then perform ack/disarm/clear only if explicitly
   confirmed safe and needed for the test record.

Pass criteria:

- Distress occurs after arming.
- Trigger/evidence references beacon/Bread or near active beacon state.
- Relay sends one emergency, not repeated duplicates.

## Scenario 3: LD2412 Occupant Detection In Van

IDs covered: `T-LD-NORMAL-02` and/or `T-LD-ARMENTRY-02`.

Normal-path procedure:

1. Start with van empty during arming if possible.
2. Turn ignition remote off and allow system to enter `armed`.
3. Adult subject enters and sits in the target seat, staying still.
4. Expected: LD2412 target passes distance/energy/sustain gate and triggers
   distress.

Arm-entry procedure:

1. Adult subject is seated before ignition-off.
2. Turn ignition remote off and allow system to enter `armed`.
3. Expected: arm-entry path uses extended sustain and then triggers if gates
   pass.

Pass criteria:

- `ld2412_target=true` and distance/energy evidence appear in telemetry.
- Distress occurs only after the configured sustain/gate behavior.
- No immediate ungated arm-entry trigger.

## Scenario 4: CO2 Rise Detection In Van

IDs covered: `T-CO2-03`.

Procedure:

1. Use only an adult volunteer, supervised continuously.
2. Record baseline CO2, door/window/fan/AC state, and cabin temperature.
3. Turn ignition remote off and allow system to arm.
4. Adult remains seated and breathing normally; stop as soon as trigger evidence
   is sufficient or abort threshold is reached.
5. Expected: CO2 rises above threshold with positive trend and triggers
   distress.

Pass criteria:

- `co2`, `co2_delta_since_armed`, and `co2_delta_3min` support the trigger.
- Distress occurs after freshness/trend/threshold conditions, not while CO2 is
  stale.
- Round stays within safety limits.

## Scenario 5: Integrated Realistic Round

IDs covered: `T-MULTI-01`.

Procedure:

1. Adult subject sits in the target seat with Bread beacon/phone near them.
2. Optional second beacon can be placed on another seat for multi-child evidence.
3. Turn ignition remote off and allow system to arm.
4. Observe which signal triggers first: BLE, LD2412, or CO2.
5. Capture one full distress cycle and relay behavior.
6. Confirm dedupe: no repeated emergency spam for the same distress id within
   the repeat interval.

Pass criteria:

- Exactly one distress cycle for the same stuck-child event.
- Emergency message contains useful evidence: bus state, trigger, beacon/child
  identity if available, LD2412/CO2 context, timestamp.
- Ack/disarm/clear workflow restores safe state after supervised cabin
  inspection.

## Suggested Order

1. Empty van false-positive baseline.
2. BLE-only beacon in van.
3. LD2412 normal path with adult subject entering after armed.
4. LD2412 arm-entry path with adult subject present before arming.
5. CO2 rise in van only if temperature and supervision are safe.
6. Integrated multi-signal round.

## Minimum Reportable Set

If time is limited, the minimum real-van evidence should be:

1. Empty van no false distress.
2. One occupied-van trigger using adult volunteer plus beacon.
3. One full Discord emergency evidence screenshot.
4. One safe recovery workflow showing final `bus/state` no active distress.

This would honestly support the claim that the prototype can detect an
occupant-like condition in a real van, while the report should still state that
testing did not involve an unattended child and did not create a heat-risk
scenario.

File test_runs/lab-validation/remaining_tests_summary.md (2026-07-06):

# Remaining Chapter 4 Tests Summary

Generated after completed run evidence in `chapter4_summary.md`.

## Covered Or Partly Covered In This Run

The list below is evidence coverage, not final requirement closure. A scenario is
"covered" only for the condition described here. Simulated MQTT publishes,
`bus_empty_on` override, Android BLE transmission, desk mmWave setup, and
passive telemetry should keep those qualifiers when copied into the report.

- `T-DISARM-02` invalid guarded-disarm rejection
- `T-DISARM-02-LATENCY` invalid command-result latency
- `T-HA-ZONE-01` simulated Home Assistant zone events
- `T-RELAY-01`, `T-RELAY-02`, `T-RELAY-03` Discord relay severity, dedupe, ack behavior
- `T-IGN-ESPNOW-01` remote unplug/replug stale recovery
- `T-IGN-RAPID-01` rapid unplug/replug no false transition
- `T-BLE-BREAD-LATENCY` automated Bread iBeacon latency
- `T-BLE-FP-ACTIVE-01` active-state BLE toggle no arming/no distress
- `T-BLE-01` armed BLE child-beacon trigger with multiple near beacons present
- `T-BLE-03` isolated Bread-only armed BLE child-beacon trigger, real Discord emergency, restored active/clear
- `T-MQTT-SOAK-01` 5-minute MQTT soak/jitter observation
- `T-MQTT-SOAK-02` 15-minute MQTT soak/jitter observation
- `T-SCD4X-PASSIVE-01` fresh passive SCD4x/CO2 telemetry and plausibility observation
- `T-LD2412-PASSIVE-01` active-state LD2412/mmWave movement-response observation; failed target-clear controllability criterion
- `T-LD-ARMENTRY-01` desk-proxy LD2412/mmWave `presence_detected` trigger with target present at arming
- `T-SHT4X-01` passive temperature/RH telemetry
- `T-GPS-01` indoor GPS fix attempt; failed because no valid fix/location was obtained
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

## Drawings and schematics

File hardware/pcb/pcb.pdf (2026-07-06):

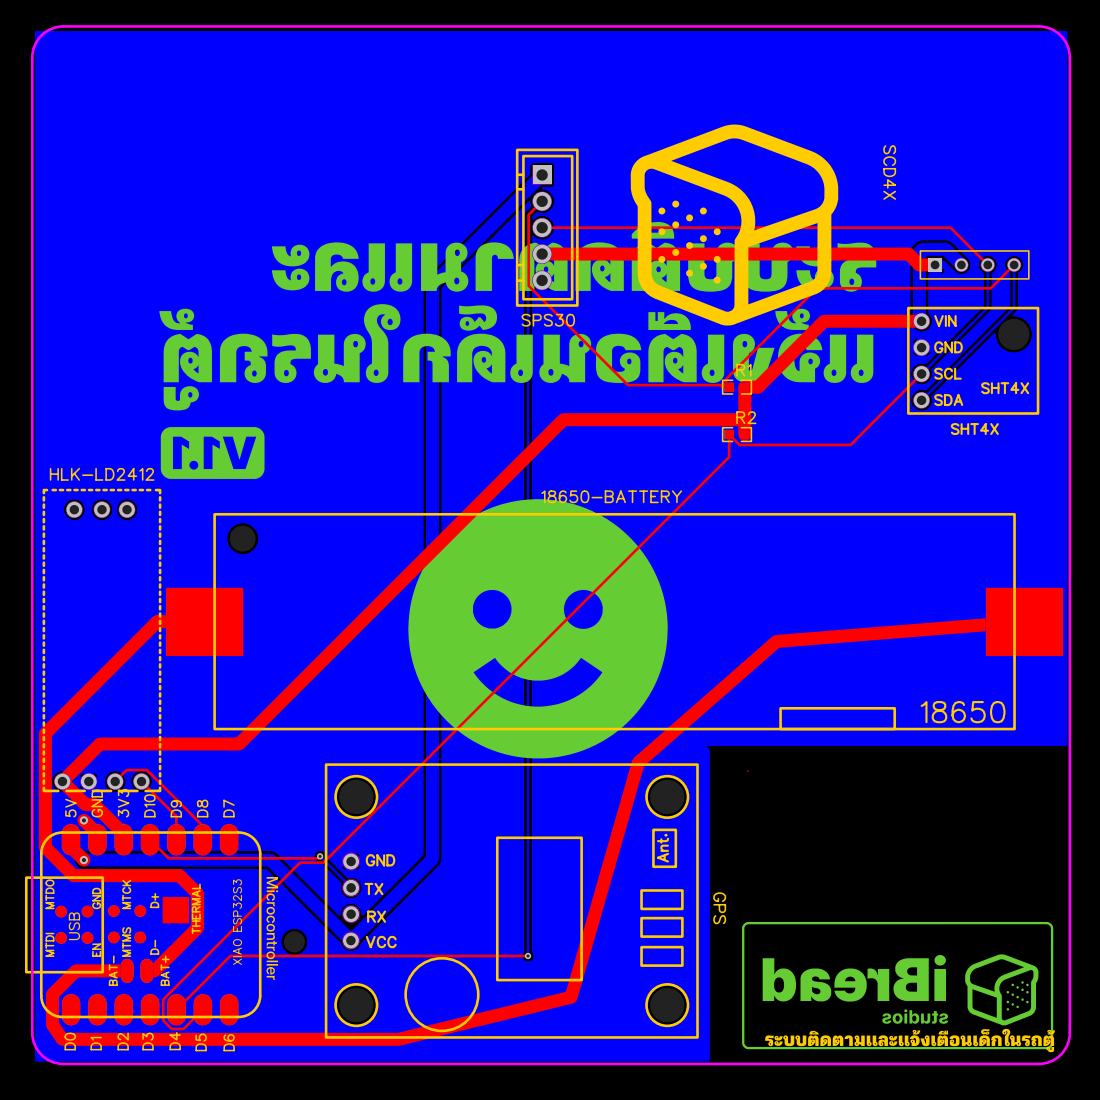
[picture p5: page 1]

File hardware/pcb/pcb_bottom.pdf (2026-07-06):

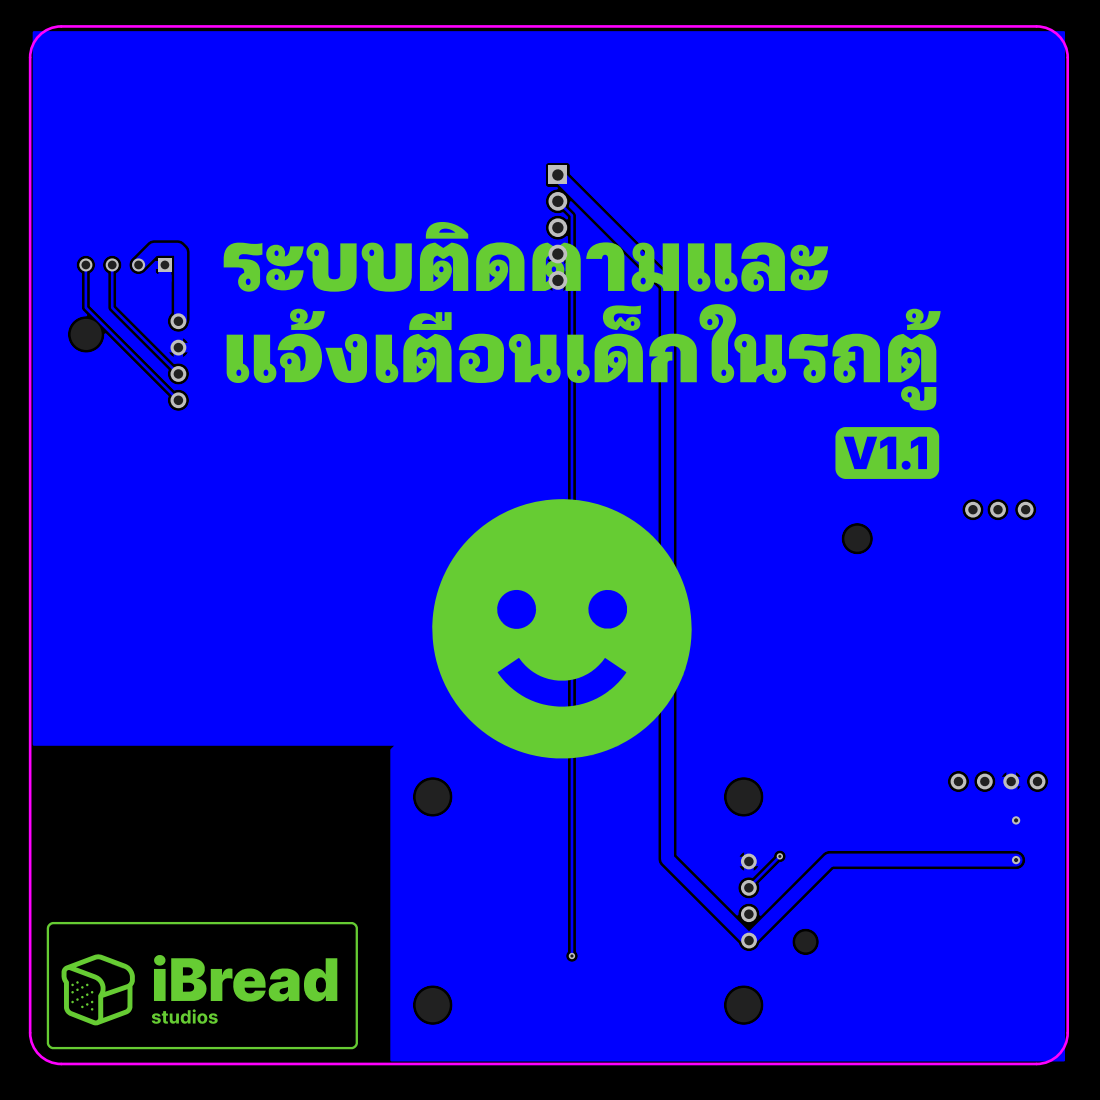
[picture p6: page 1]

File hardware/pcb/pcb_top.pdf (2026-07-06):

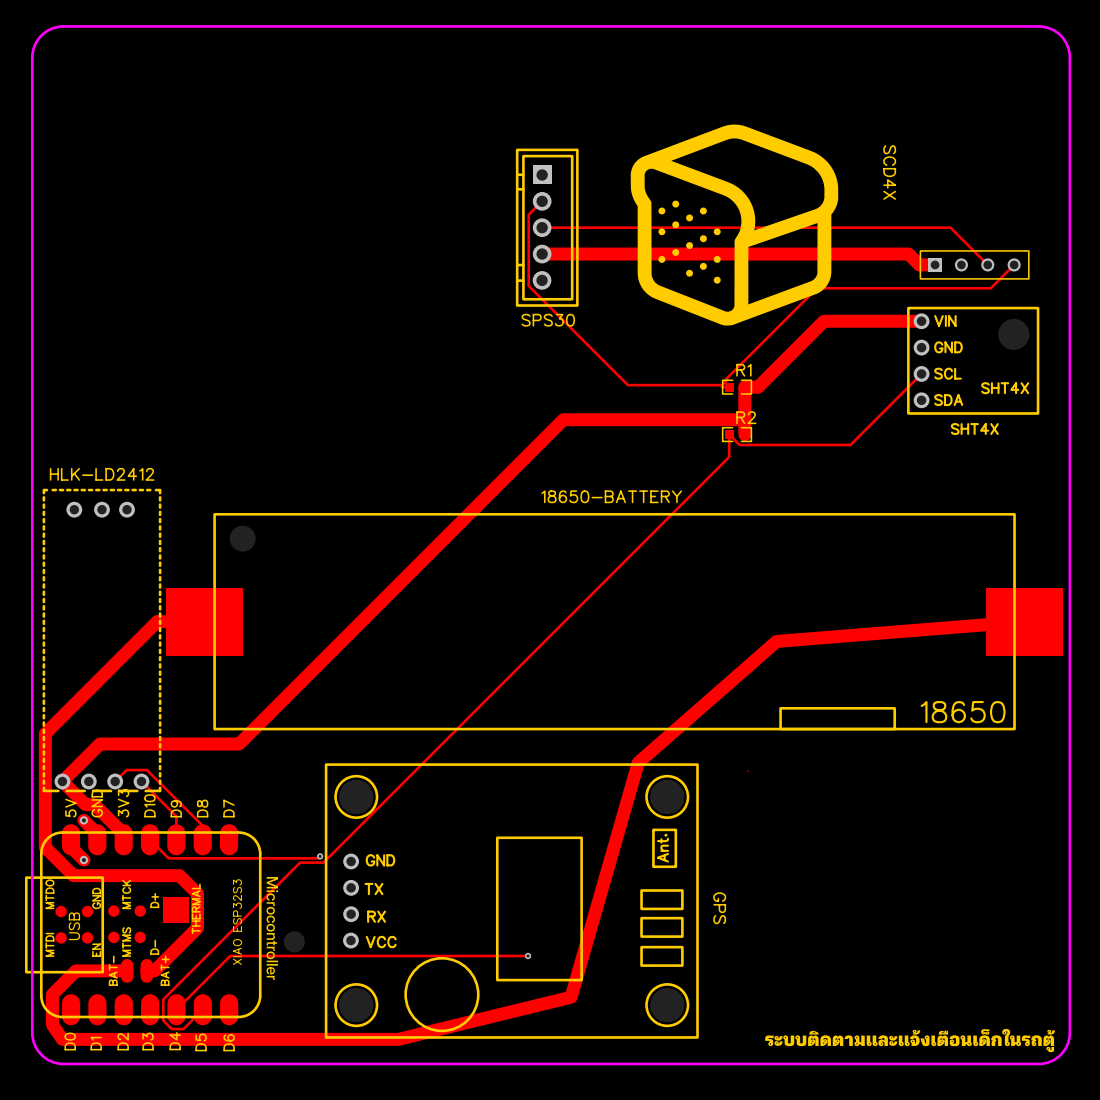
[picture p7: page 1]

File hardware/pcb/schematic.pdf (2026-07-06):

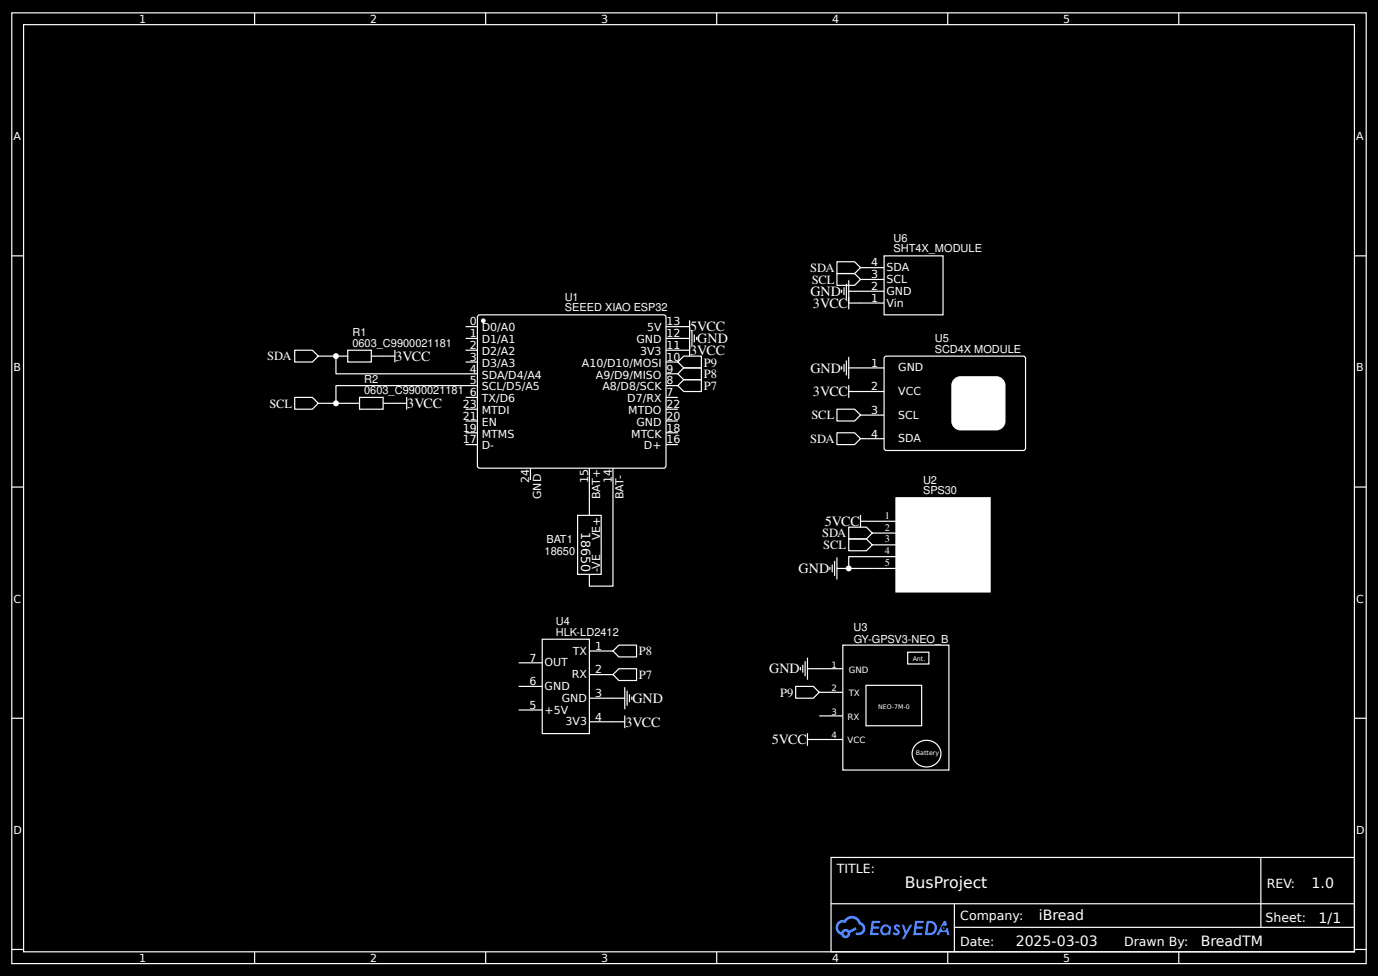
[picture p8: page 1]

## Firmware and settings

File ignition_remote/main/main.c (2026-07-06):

/* Ignition Remote
 *
 * Dumb heartbeat broadcaster for the VanChildSafety ignition-detection system.
 * This ESP32 is wired to the vehicle's ignition/accessory power rail: when
 * ignition is on, it boots and broadcasts an ESP-NOW heartbeat every
 * CONFIG_ESPNOW_HEARTBEAT_INTERVAL_MS. When ignition turns off, it loses
 * power and the heartbeats stop; the main firmware declares ignition off
 * after CONFIG_ESPNOW_HEARTBEAT_TIMEOUT_MS of silence.
 *
 * The remote never associates WiFi, has no MQTT, no OTA. It only brings up
 * the WiFi radio (unassociated, STA mode) so ESP-NOW operates, then broadcasts.
 *
 * The shared protocol header (../main/ignition_espnow_protocol.h) defines
 * the wire format; both sides must use the same CONFIG_ESPNOW_SECRET. */

#include <string.h>
#include "esp_log.h"
#include "esp_timer.h"
#include "esp_wifi.h"
#include "esp_now.h"
#include "esp_netif.h"
#include "esp_event.h"
#include "nvs_flash.h"
#include "freertos/FreeRTOS.h"
#include "freertos/task.h"
#include "freertos/event_groups.h"

#include "ignition_espnow_protocol.h"

static const char *TAG = "IGN_REMOTE";

#define HEARTBEAT_INTERVAL_US (CONFIG_ESPNOW_HEARTBEAT_INTERVAL_MS * 1000LL)
#define ESPNOW_MIN_CHANNEL 1
#define ESPNOW_MAX_CHANNEL 13
#define CHANNEL_SWEEP_DELAY_MS 20

static uint32_t s_magic = 0;
static uint16_t s_seq = 0;
static EventGroupHandle_t s_events;
#define WIFI_READY_BIT BIT0

static uint32_t fnv1a32(const char *s)
{
    uint32_t h = 0x811c9dc5u;
    while (s && *s) {
        h ^= (uint8_t)*s++;
        h *= 0x01000193u;
    }
    return h;
}

static void wifi_event_handler(void *arg, esp_event_base_t base,
                               int32_t id, void *data)
{
    if (base == WIFI_EVENT && id == WIFI_EVENT_STA_START) {
        /* Don't connect to an AP; just start the radio so ESP-NOW works. */
        xEventGroupSetBits(s_events, WIFI_READY_BIT);
        ESP_LOGI(TAG, "WiFi started (unassociated) - ESP-NOW ready");
    }
}

static uint16_t read_battery_mv(void)
{
#if CONFIG_ESPNOW_BATTERY_ADC_CHANNEL >= 0
    /* TODO: implement with esp_adc/oneshot driver reading ADC1 channel
     * CONFIG_ESPNOW_BATTERY_ADC_CHANNEL and scaling by your divider ratio.
     * Returning 0 here keeps the telemetry contract valid (battery=0 means
     * "not measured this frame") without blocking the heartbeat path. */
    return 0;
#else
    /* Battery monitoring disabled; remote reports 0 in every heartbeat. The
     * main surfaces this as `remote_battery_mv: 0` in bus/state — HA shows 0,
     * which correctly means "no ADC configured" rather than a real 0 mV. */
    return 0;
#endif
}

static void send_heartbeat_on_channel(uint8_t channel,
                                      const uint8_t *peer_addr,
                                      const ignition_heartbeat_t *hb)
{
    wifi_second_chan_t sec = WIFI_SECOND_CHAN_NONE;
    esp_err_t ch = esp_wifi_set_channel(channel, sec);
    if (ch != ESP_OK) {
        ESP_LOGW(TAG, "esp_wifi_set_channel(%u) failed: %s",
                 channel, esp_err_to_name(ch));
        return;
    }

    esp_err_t r = esp_now_send(peer_addr, (const uint8_t *)hb, sizeof(*hb));
    if (r != ESP_OK) {
        ESP_LOGW(TAG, "esp_now_send(ch=%u) failed: %s",
                 channel, esp_err_to_name(r));
    }
}

void app_main(void)
{
    ESP_LOGI(TAG, "Ignition remote starting (interval=%dms)",
             CONFIG_ESPNOW_HEARTBEAT_INTERVAL_MS);

    /* NVS init (ESP-NOW / WiFi may use it). */
    esp_err_t ret = nvs_flash_init();
    if (ret == ESP_ERR_NVS_NO_FREE_PAGES || ret == ESP_ERR_NVS_NEW_VERSION_FOUND) {
        nvs_flash_erase();
        nvs_flash_init();
    }

    s_events = xEventGroupCreate();

    ESP_ERROR_CHECK(esp_netif_init());
    ESP_ERROR_CHECK(esp_event_loop_create_default());

    /* Minimal WiFi init: STA mode, started but never connected. ESP-NOW
     * rides on the WiFi radio without association. */
    esp_netif_create_default_wifi_sta();
    wifi_init_config_t cfg = WIFI_INIT_CONFIG_DEFAULT();
    ESP_ERROR_CHECK(esp_wifi_init(&cfg));

    ESP_ERROR_CHECK(esp_event_handler_instance_register(
        WIFI_EVENT, ESP_EVENT_ANY_ID, &wifi_event_handler, NULL, NULL));

    ESP_ERROR_CHECK(esp_wifi_set_mode(WIFI_MODE_STA));
    ESP_ERROR_CHECK(esp_wifi_start());
    /* WIFI_EVENT_STA_START fires -> WIFI_READY_BIT set by event handler. */

    /* Wait for the radio to be up, then init ESP-NOW. */
    xEventGroupWaitBits(s_events, WIFI_READY_BIT, pdFALSE, pdTRUE, portMAX_DELAY);

    s_magic = fnv1a32(CONFIG_ESPNOW_SECRET);

    esp_err_t en = esp_now_init();
    if (en != ESP_OK) {
        ESP_LOGE(TAG, "esp_now_init failed: %s", esp_err_to_name(en));
        /* Nothing useful to do without ESP-NOW; reboot after a delay. */
        vTaskDelay(pdMS_TO_TICKS(5000));
        esp_restart();
    }

    /* Add the broadcast peer so our frames reach the main receiver. */
    esp_now_peer_info_t peer = {0};
    /* Channel 0 means "current WiFi channel"; send_heartbeat_on_channel()
     * moves the unassociated radio before each broadcast. */
    peer.channel = 0;
    peer.ifidx = WIFI_IF_STA;
    memset(peer.peer_addr, 0xFF, ESP_NOW_ETH_ALEN);
    en = esp_now_add_peer(&peer);
    if (en != ESP_OK && en != ESP_ERR_ESPNOW_EXIST) {
        ESP_LOGW(TAG, "esp_now_add_peer(broadcast) failed: %s", esp_err_to_name(en));
    }

    if (CONFIG_ESPNOW_CHANNEL == 0) {
        ESP_LOGI(TAG, "Broadcasting heartbeats on channels %d-%d (magic=0x%08lx)",
                 ESPNOW_MIN_CHANNEL, ESPNOW_MAX_CHANNEL, (unsigned long)s_magic);
    } else {
        ESP_LOGI(TAG, "Broadcasting heartbeats on fixed channel %d (magic=0x%08lx)",
                 CONFIG_ESPNOW_CHANNEL, (unsigned long)s_magic);
    }

    /* Heartbeat loop. While powered (ignition on), broadcast every interval.
     * Losing power (ignition off) stops the loop; the main firmware's timeout
     * handles the silent period. */
    while (1) {
        ignition_heartbeat_t hb = {
            .magic = s_magic,
            .seq = s_seq,
            .uptime_s = (uint32_t)(esp_timer_get_time() / 1000000LL),
            .battery_mv = read_battery_mv(),
        };
        s_seq++;

        if (CONFIG_ESPNOW_CHANNEL == 0) {
            for (uint8_t channel = ESPNOW_MIN_CHANNEL;
                 channel <= ESPNOW_MAX_CHANNEL;
                 channel++) {
                send_heartbeat_on_channel(channel, peer.peer_addr, &hb);
                vTaskDelay(pdMS_TO_TICKS(CHANNEL_SWEEP_DELAY_MS));
            }
        } else {
            send_heartbeat_on_channel(CONFIG_ESPNOW_CHANNEL, peer.peer_addr, &hb);
        }

        vTaskDelay(pdMS_TO_TICKS(CONFIG_ESPNOW_HEARTBEAT_INTERVAL_MS));
    }
}

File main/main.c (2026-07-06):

#include <string.h>
#include "nvs_flash.h"
#include "esp_netif.h"
#include "esp_event.h"
#include "esp_log.h"
#include "esp_timer.h"
#include "common.h"
#include "wifi.h"
#include "ntp_sync.h"
#include "wireguard.h"
#include "bus_mqtt.h"
#include "bus_state.h"
#include "i2c_bus.h"
#include "sensor_sht4x.h"
#include "sensor_scd4x.h"
#include "sensor_ld2412.h"
#include "sensor_gps.h"
#include "co2_tracker.h"
#include "ble_scanner.h"
#include "beacon_config.h"
#include "notifications.h"
#include "ota_server.h"

static const char *TAG = "MAIN";

static void status_watchdog_task(void *pvParameters)
{
    while (1) {
        vTaskDelay(pdMS_TO_TICKS(10000));
        EventBits_t bits = xEventGroupGetBits(g_event_group);
        ESP_LOGI(TAG, "STATUS uptime=%lus wifi=%d ntp=%d wg=%d mqtt=%d heap=%lu",
                 (unsigned long)(esp_timer_get_time() / 1000000),
                 !!(bits & WIFI_CONNECTED_BIT),
                 !!(bits & NTP_SYNCED_BIT),
                 !!(bits & WG_CONNECTED_BIT),
                 !!(bits & MQTT_CONNECTED_BIT),
                 (unsigned long)esp_get_free_heap_size());
    }
}

EventGroupHandle_t g_event_group;
SemaphoreHandle_t g_telemetry_mutex;
QueueHandle_t g_distress_queue;
QueueHandle_t g_co2_queue;
telemetry_data_t g_telemetry;
volatile bool g_bus_empty;

void app_main(void)
{
    ESP_LOGI(TAG, "VanChildSafety starting...");

    esp_err_t ret = nvs_flash_init();
    if (ret == ESP_ERR_NVS_NO_FREE_PAGES || ret == ESP_ERR_NVS_NEW_VERSION_FOUND) {
        ESP_ERROR_CHECK(nvs_flash_erase());
        ret = nvs_flash_init();
    }
    ESP_ERROR_CHECK(ret);

    ESP_ERROR_CHECK(esp_netif_init());
    ESP_ERROR_CHECK(esp_event_loop_create_default());

    g_event_group = xEventGroupCreate();
    g_telemetry_mutex = xSemaphoreCreateMutex();
    g_distress_queue = xQueueCreate(20, sizeof(distress_event_t));
    g_co2_queue = xQueueCreate(1, sizeof(uint16_t));
    if (!g_event_group || !g_telemetry_mutex || !g_distress_queue || !g_co2_queue) {
        ESP_LOGE(TAG, "Failed to create FreeRTOS objects");
        esp_restart();
    }
    memset(&g_telemetry, 0, sizeof(g_telemetry));
    g_bus_empty = false;

    i2c_bus_init();
    beacon_config_init();

    xTaskCreate(wifi_task, "wifi_task", 4096, NULL, 5, NULL);
    xTaskCreate(ntp_sync_task, "ntp_sync_task", 4096, NULL, 4, NULL);
    xTaskCreate(wireguard_task, "wireguard_task", 10240, NULL, 4, NULL);
    xTaskCreate(mqtt_task, "mqtt_task", 6144, NULL, 4, NULL);
    xTaskCreate(bus_state_task, "bus_state_task", 4096, NULL, 4, NULL);
    xTaskCreate(sensor_i2c_task, "sensor_i2c_task", 4096, NULL, 3, NULL);
    xTaskCreate(ld2412_task, "ld2412_task", 3072, NULL, 3, NULL);
    xTaskCreate(gps_task, "gps_task", 3072, NULL, 3, NULL);
    xTaskCreate(co2_tracker_task, "co2_tracker_task", 4096, NULL, 3, NULL);
    xTaskCreate(ble_scan_task, "ble_scan_task", 4096, NULL, 4, NULL);
    xTaskCreate(notification_task, "notification_task", 8192, NULL, 3, NULL);
    xTaskCreate(status_watchdog_task, "status_watchdog", 3072, NULL, 1, NULL);
    xTaskCreate(ota_server_task, "ota_server_task", 12288, NULL, 3, NULL);

    ESP_LOGI(TAG, "All tasks created.");
    vTaskDelete(NULL);
}

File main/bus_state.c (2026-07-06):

#include <string.h>
#include <time.h>
#include <sys/time.h>
#include "esp_log.h"
#include "esp_timer.h"
#include "freertos/FreeRTOS.h"
#include "freertos/task.h"
#include "cJSON.h"
#include "common.h"
#include "bus_state.h"
#include "bus_mqtt.h"
#include "beacon_config.h"
#include "notifications.h"
#include "ignition.h"

static const char *TAG = "BUS_STATE";

#define EXIT_GRACE_S        CONFIG_EXIT_GRACE_SECONDS
#define CO2_BASELINE_STALE_S 90

static portMUX_TYPE s_lock = portMUX_INITIALIZER_UNLOCKED;
static bus_state_t s_state = BUS_STATE_BOOT;
static bool s_ignition_on = false;
/* Override layer above ignition_get(). Set by bus_state_force_empty(); cleared
 * when ignition_get() reports a value different from the override value AND
 * it's debounced-stable (i.e. a real source edge). This fixes a latent bug
 * where force_empty set s_ignition_on directly and the next GPIO poll would
 * silently overwrite it, leaving bus_state_ignition_on() reporting the real
 * GPIO value while the override-intended state was lost. */
static bool s_override_active = false;
static bool s_override_value = false;
/* Previous poll's debounced source value, for real-edge detection when an
 * override is active. The override is cleared when the source's debounced
 * value *changes* (s_last_raw -> raw), not merely when it differs from the
 * override value — this honors "override lasts until next ignition edge". */
static bool s_last_raw = false;
/* Previous poll's effective ignition value (override-applied). Kept at file
 * scope so bus_state_force_empty() can reset it after installing an override,
 * preventing the poll loop from re-triggering a transition force_empty
 * already handled via enter_armed()/enter_state(ACTIVE). */
static bool s_prev_effective = false;
static bool s_distress_active = false;
static bool s_distress_acknowledged = false;
static int64_t s_exit_grace_started = 0;
static uint32_t s_armed_generation = 0;
static uint16_t s_co2_baseline = 0;
static char s_distress_id[48] = {0};
static int64_t s_fault_started_at = 0;
static bool s_fault_reported = false;

static void set_telemetry_state_locked(void)
{
    if (xSemaphoreTake(g_telemetry_mutex, pdMS_TO_TICKS(100)) == pdTRUE) {
        g_telemetry.ignition_on = s_ignition_on;
        g_telemetry.bus_armed = (s_state == BUS_STATE_ARMED ||
                                s_state == BUS_STATE_DISTRESS_PENDING ||
                                s_state == BUS_STATE_DISTRESS_ACTIVE ||
                                s_state == BUS_STATE_ACKED);
        strncpy(g_telemetry.bus_state, bus_state_name(s_state),
                sizeof(g_telemetry.bus_state) - 1);
        g_telemetry.bus_state[sizeof(g_telemetry.bus_state) - 1] = '\0';
        g_telemetry.co2_baseline = s_co2_baseline;
        xSemaphoreGive(g_telemetry_mutex);
    }
}

const char *bus_state_name(bus_state_t state)
{
    switch (state) {
    case BUS_STATE_BOOT: return "boot";
    case BUS_STATE_ACTIVE: return "active";
    case BUS_STATE_EXIT_GRACE: return "exit_grace";
    case BUS_STATE_ARMED: return "armed";
    case BUS_STATE_DISTRESS_PENDING: return "distress_pending";
    case BUS_STATE_DISTRESS_ACTIVE: return "distress_active";
    case BUS_STATE_ACKED: return "acked";
    case BUS_STATE_DISARMED: return "disarmed";
    case BUS_STATE_FAULT: return "fault";
    default: return "unknown";
    }
}

bus_state_t bus_state_get(void)
{
    bus_state_t state;
    portENTER_CRITICAL(&s_lock);
    state = s_state;
    portEXIT_CRITICAL(&s_lock);
    return state;
}

bool bus_state_is_armed(void)
{
    bus_state_t state = bus_state_get();
    return state == BUS_STATE_ARMED || state == BUS_STATE_DISTRESS_PENDING ||
           state == BUS_STATE_DISTRESS_ACTIVE || state == BUS_STATE_ACKED;
}

bool bus_state_allows_attendance(void)
{
    bus_state_t state = bus_state_get();
    return state == BUS_STATE_ACTIVE || state == BUS_STATE_EXIT_GRACE;
}

bool bus_state_ignition_on(void)
{
    bool ignition;
    portENTER_CRITICAL(&s_lock);
    ignition = s_ignition_on;
    portEXIT_CRITICAL(&s_lock);
    return ignition;
}

bool bus_state_distress_active(void)
{
    bool active;
    portENTER_CRITICAL(&s_lock);
    active = s_distress_active;
    portEXIT_CRITICAL(&s_lock);
    return active;
}

bool bus_state_distress_acknowledged(void)
{
    bool acked;
    portENTER_CRITICAL(&s_lock);
    acked = s_distress_acknowledged;
    portEXIT_CRITICAL(&s_lock);
    return acked;
}

int bus_state_exit_grace_remaining_s(void)
{
    int remaining = 0;
    portENTER_CRITICAL(&s_lock);
    if (s_state == BUS_STATE_EXIT_GRACE && s_exit_grace_started > 0) {
        int64_t elapsed = (esp_timer_get_time() - s_exit_grace_started) / 1000000;
        remaining = EXIT_GRACE_S - (int)elapsed;
        if (remaining < 0) remaining = 0;
    }
    portEXIT_CRITICAL(&s_lock);
    return remaining;
}

uint32_t bus_state_armed_generation(void)
{
    uint32_t generation;
    portENTER_CRITICAL(&s_lock);
    generation = s_armed_generation;
    portEXIT_CRITICAL(&s_lock);
    return generation;
}

static void generate_distress_id_locked(void)
{
    struct timeval tv;
    gettimeofday(&tv, NULL);
    struct tm tm_buf;
    gmtime_r(&tv.tv_sec, &tm_buf);
    strftime(s_distress_id, sizeof(s_distress_id), "distress-%Y%m%d-%H%M%S", &tm_buf);
}

const char *bus_state_distress_id(void)
{
    const char *id;
    portENTER_CRITICAL(&s_lock);
    id = s_distress_id[0] ? s_distress_id : NULL;
    portEXIT_CRITICAL(&s_lock);
    return id;
}

void bus_state_set_co2_baseline(uint16_t co2)
{
    portENTER_CRITICAL(&s_lock);
    s_co2_baseline = co2;
    portEXIT_CRITICAL(&s_lock);
    set_telemetry_state_locked();
}

uint16_t bus_state_co2_baseline(void)
{
    uint16_t baseline;
    portENTER_CRITICAL(&s_lock);
    baseline = s_co2_baseline;
    portEXIT_CRITICAL(&s_lock);
    return baseline;
}

static void publish_simple_event(const char *event)
{
    cJSON *root = cJSON_CreateObject();
    if (!root) return;
    cJSON_AddStringToObject(root, "event", event);
    cJSON_AddStringToObject(root, "state", bus_state_name(bus_state_get()));
    mqtt_publish_event_json(root);
    cJSON_Delete(root);
}

static void publish_sensor_fault_event(const char *sensor, const char *detail, int duration_s)
{
    cJSON *root = cJSON_CreateObject();
    if (!root) return;
    cJSON_AddStringToObject(root, "event", "sensor_fault");
    cJSON_AddStringToObject(root, "state", bus_state_name(bus_state_get()));
    cJSON_AddStringToObject(root, "sensor", sensor ? sensor : "unknown");
    cJSON_AddStringToObject(root, "detail", detail ? detail : "unknown");
    cJSON_AddNumberToObject(root, "duration_s", duration_s);
    mqtt_publish_event_json(root);
    cJSON_Delete(root);
}
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

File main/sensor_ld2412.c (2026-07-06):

#include <string.h>
#include "driver/uart.h"
#include "esp_log.h"
#include "esp_timer.h"
#include "freertos/FreeRTOS.h"
#include "freertos/task.h"
#include "common.h"
#include "bus_state.h"
#include "sensor_ld2412.h"

static const char *TAG = "LD2412";

static int s_frame_count = 0;
static int s_byte_count = 0;
static int64_t s_last_log = 0;

typedef enum {
    ST_IDLE, ST_H1, ST_H2, ST_H3,
    ST_LEN1, ST_LEN2, ST_CMD1, ST_CMD2,
    ST_DATA, ST_E1, ST_E2, ST_E3, ST_E4,
} parser_state_t;

static int s_state = ST_IDLE;
static uint8_t s_data[64];
static int s_data_idx = 0;
static uint16_t s_data_len = 0;
static uint16_t s_cmd = 0;
static uint8_t s_std_type = 0;
static int64_t s_target_since = 0;
static uint32_t s_reported_generation = 0;
static uint32_t s_seen_armed_generation = 0;
static int64_t s_target_dropped_at = 0;  /* 0 = not currently in drop-debounce */
static bool s_target_was_present_at_arm = false;

#define PRESENCE_SUSTAIN_S CONFIG_PRESENCE_SUSTAIN_S
#define PRESENCE_SUSTAIN_ARMED_EXISTING_S CONFIG_PRESENCE_SUSTAIN_ARMED_EXISTING_S
#define PRESENCE_TARGET_DROP_DEBOUNCE_MS CONFIG_PRESENCE_TARGET_DROP_DEBOUNCE_MS
#define PRESENCE_STILL_DISTANCE_MAX_CM CONFIG_PRESENCE_STILL_DISTANCE_MAX_CM
#define PRESENCE_STILL_ENERGY_MIN CONFIG_PRESENCE_STILL_ENERGY_MIN

/* Loaded at task start from Kconfig so the compiler can't fold the gate
 * comparisons into dead-code-in-calendar (which it would for the
 * PRESENCE_STILL_ENERGY_MIN=0 default, generating a -Wtype-limits warning
 * for the uint8_t < 0 check). */
static int s_sustain_s = PRESENCE_SUSTAIN_S;
static int s_sustain_armed_existing_s = PRESENCE_SUSTAIN_ARMED_EXISTING_S;
static int s_drop_debounce_ms = PRESENCE_TARGET_DROP_DEBOUNCE_MS;
static int s_still_distance_max_cm = PRESENCE_STILL_DISTANCE_MAX_CM;
static int s_still_energy_min = PRESENCE_STILL_ENERGY_MIN;

static void evaluate_presence_trigger(bool has_target, uint16_t still_distance,
                                       uint8_t still_energy);

#define ST_F4_HDR  50
#define ST_F4_F3   51
#define ST_F4_F2   52
#define ST_F4_F1   53
#define ST_SD_LENL 54
#define ST_SD_LENH 55
#define ST_SD_TYPE 56
#define ST_SD_AA   57
#define ST_SD_DATA 58
#define ST_SD_F8   59
#define ST_SD_F7   60
#define ST_SD_F6   61
#define ST_SD_F5   62

static void process_frame_eng(uint16_t cmd, const uint8_t *data, int len)
{
    if ((cmd == 0xAA02 || cmd == 0x0101) && len >= 9) {
        bool has_target = data[0] != 0;
        bool has_moving = (data[0] == 1 || data[0] == 3);
        bool has_still = (data[0] == 2 || data[0] == 3);
        uint16_t moving_dist = data[1] | (data[2] << 8);
        uint8_t moving_energy = data[3];
        uint16_t still_dist = data[4] | (data[5] << 8);
        uint8_t still_energy = data[6];
        uint16_t detect_dist = 0;
        if (len >= 9) detect_dist = data[7] | (data[8] << 8);

        if (xSemaphoreTake(g_telemetry_mutex, pdMS_TO_TICKS(100)) == pdTRUE) {
            g_telemetry.ld2412_target = has_target;
            g_telemetry.ld2412_moving = has_moving;
            g_telemetry.ld2412_still = has_still;
            g_telemetry.moving_distance = moving_dist;
            g_telemetry.still_distance = still_dist;
            g_telemetry.moving_energy = moving_energy;
            g_telemetry.still_energy = still_energy;
            g_telemetry.detection_distance = detect_dist;
            g_telemetry.ld2412_last_frame_us = esp_timer_get_time();
            xSemaphoreGive(g_telemetry_mutex);
        }

        s_frame_count++;
        evaluate_presence_trigger(has_target, still_dist, still_energy);
    }
}

static void evaluate_presence_trigger(bool has_target, uint16_t still_distance,
                                       uint8_t still_energy)
{
    int64_t now = esp_timer_get_time();
    uint32_t generation = bus_state_armed_generation();

    /* Track arm-time snapshot: when the armed generation changes, record
     * whether the target was already present at that moment. If it was,
     * require a longer sustain to reject the driver's residual signature. */
    if (generation != s_seen_armed_generation) {
        s_seen_armed_generation = generation;
        s_reported_generation = 0;
        s_target_was_present_at_arm = has_target;
        if (has_target) {
            s_target_since = now;
            s_target_dropped_at = 0;
        }
        /* Measure dwell from the armed boundary for targets already present
         * at arming. Otherwise a driver/radar residual that existed before
         * arming can satisfy the sustain timer immediately. */
    }

    if (has_target) {
        /* Clear any in-progress drop debounce; target is back. */
        s_target_dropped_at = 0;
        if (s_target_since == 0) s_target_since = now;
    } else {
        /* Debounce: real frames can briefly report has_target=0 during a
         * still/moving handoff. Require a sustained drop before clearing
         * s_target_since, so a one-frame blip doesn't reset the sustain
         * timer and force a fresh 5s before re-triggering. */
        if (s_target_dropped_at == 0) {
            s_target_dropped_at = now;
            return;
        }
        if ((now - s_target_dropped_at) < (int64_t)s_drop_debounce_ms * 1000LL) {
            return;
        }
        s_target_since = 0;
        s_target_dropped_at = 0;
        s_reported_generation = 0;
        if (xSemaphoreTake(g_telemetry_mutex, pdMS_TO_TICKS(100)) == pdTRUE) {
            g_telemetry.ld2412_target_since_us = 0;
            xSemaphoreGive(g_telemetry_mutex);
        }
        return;
    }

    if (xSemaphoreTake(g_telemetry_mutex, pdMS_TO_TICKS(100)) == pdTRUE) {
        g_telemetry.ld2412_target_since_us = s_target_since;
        xSemaphoreGive(g_telemetry_mutex);
    }

    if (!bus_state_is_armed() || generation == 0 || s_reported_generation == generation) return;

    /* Distance gate: a child seat is usually within ~1.5m of the radar.
     * A still target beyond the configured max distance is likely a far
     * reflection (dashboard, roof) and shouldn't trigger. */
    if (s_still_distance_max_cm < 9999 && (int)still_distance > s_still_distance_max_cm) {
        return;
    }
    /* Energy gate: ignore near-zero energy still targets (radar noise floor). */
    if (s_still_energy_min > 0 && (int)still_energy < s_still_energy_min) {
        return;
    }
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
